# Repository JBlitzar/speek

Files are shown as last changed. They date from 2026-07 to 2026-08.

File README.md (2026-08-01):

# speek

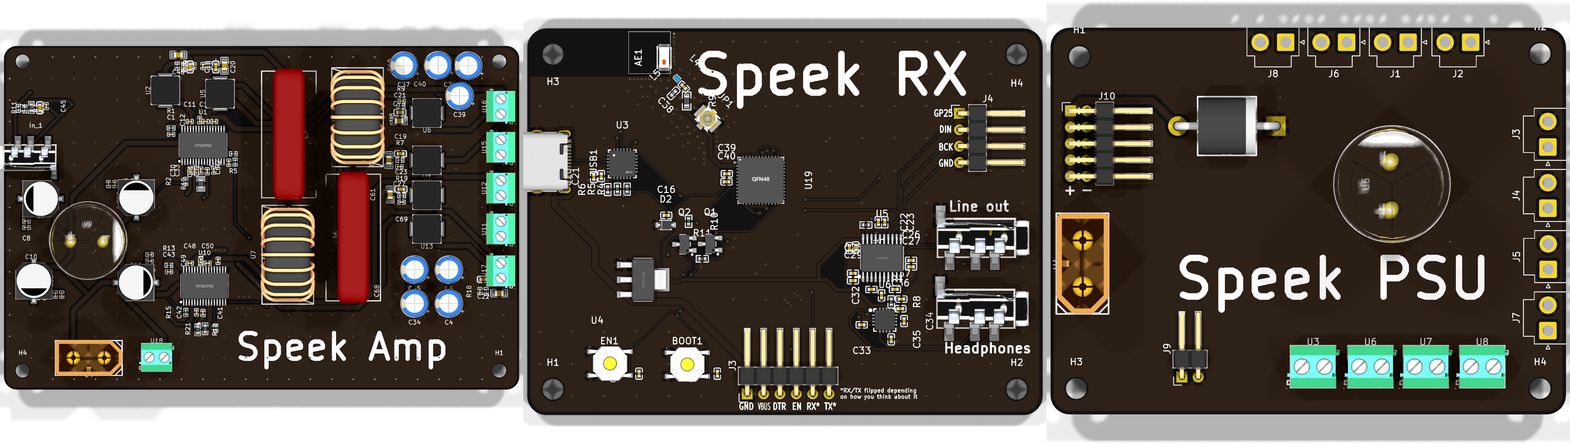
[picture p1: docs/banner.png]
speek


A modular speaker system. Right now, it has a couple of boards:

- Speek Amp: This is the flagship amplifier. It's a hybrid 2.1 design using the TPA3116D2 chip. It's built to handle 4Ω speakers. It outputs lines for a mono subwoofer, two stereo woofers, and two stereo tweeters.
- Speek RX: This is a Bluetooth audio receiver. It runs off of a qfn esp32 D0WD v3 and has a built-in headphone amp, or a normal line out for chaining.
- Speek PSU: This is a supporting PSU board. It has a USB-C PD trigger (for quick tests) and a barrel jack port for proper power (needed to power real flagship drivers). It can be used as a stable power source for pretty much anything. Note that the barrel jack supplies 24V while PD gives 20V. 

On modularity:

- Each board is self-contained and can be used on its own. However, they can also all be used together. 

I made this project to get into audio systems! I've visited some hi-fi listening rooms, and I thought it was really cool. But I think the speaker industry is way overpriced. People commonly pay several thousand dollars for nice speaker systems! I wanted to build one myself for a few hundred. It might not be as high-fidelity, but it'll be my own, which is pretty cool. And you or I probably wouldn't be able to hear the difference. 

**Right now, enclosure design is out of scope. This repo holds just the boards, and the boards are complete**

## \[Please Read\] Where do I find everything? AKA checklist

What's with the monorepo?

A monorepo just means everything lives in one repo instead of splitting each board into its own. All the files are here: each board gets its own top-level folder (`speek-amp`, `speek-rx`, `speek-psu`), with docs in `docs` and the overall BOM at `BOM.csv`. I went with a monorepo because even though there are multiple boards, it's really one project overall, so it made sense to keep them together.

Checklist:

- [x] A good README
- [x] Source files for your project
    - This includes hardware design, firmware, 3D assemblies, etc
- [x] Production files (if applicable)
    - You'll find gerbers, fabrication BOMs, and PnP files at the following locations:
      - Speek Amp: [speek-amp/PCB/speek_amp/production_real](speek-amp/PCB/speek_amp/production_real)
      - Speek RX: [speek-rx/PCB/speek_rx/production_real](speek-rx/PCB/speek_rx/production_real)
      - Speek PSU: [speek-psu/PCB/speek_psu/production_real](speek-psu/PCB/speek_psu/production_real)
- \[N/A\] JOURNAL.md if journalling on Git
- [x] BOM.csv complete with functioning links (where applicable)
- [x] A short description of what your project is
- [x] A couple sentences on why you made the project
- [x] PICTURES OF YOUR PROJECT
- [x] A screenshot of your PCB, if you have one
- [x] A screenshot of your schematic, if you have one
- [x] A wiring diagram, if you're doing any wiring that isn't on a PCB
- [x] A BOM in table format at the end of the README
- [x] A STEP file of your assembly: [speek_assembly.step](docs/speek_assembly.step)

## How to use?

Mostly it's plug-and-play after assembling everything. The exception is Speek RX, which requires firmware to be flashed. See [speek-rx/README.md](speek-rx/README.md) for more info, but in short, all you should need to do is

```bash
cd speek-rx
cd firmware
pio run -t upload
```

For wiring your speaker drivers, the silkscreen should coach you through that. 

## Wiring Diagram

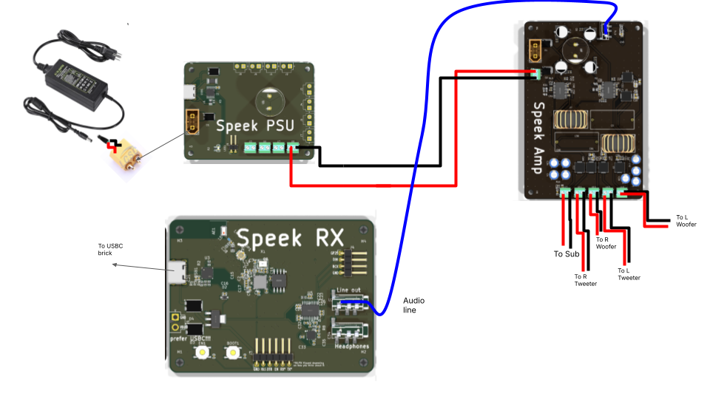
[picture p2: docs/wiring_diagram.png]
Wiring Diagram


## Gallery

### Speek Amp

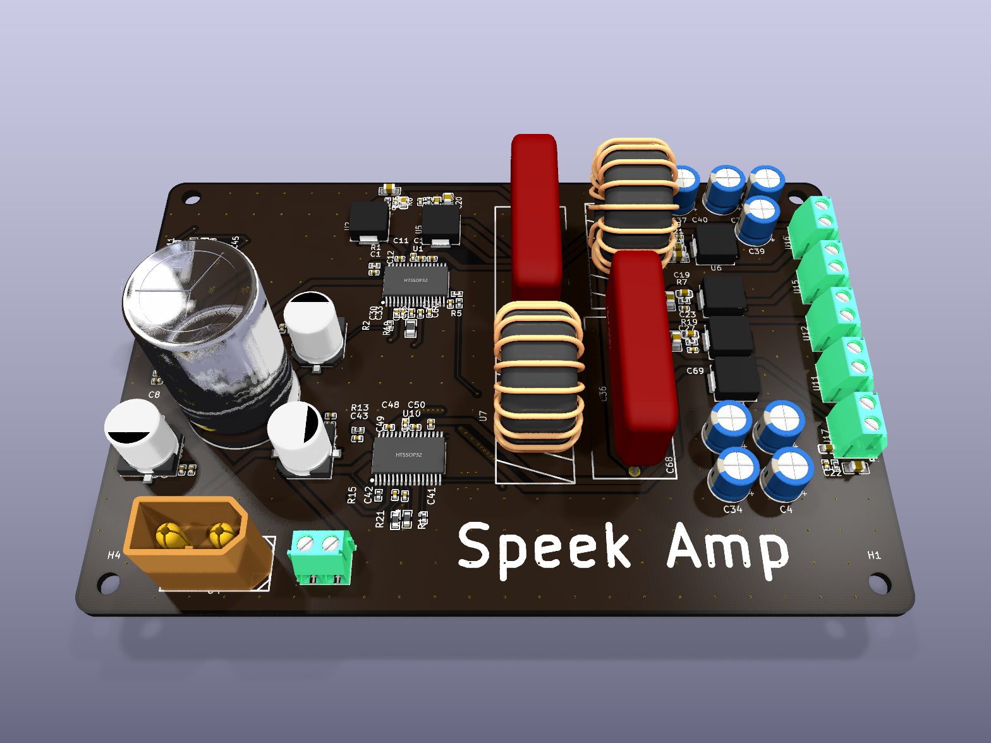
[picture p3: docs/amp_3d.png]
Speek Amp 3D render


### Speek RX

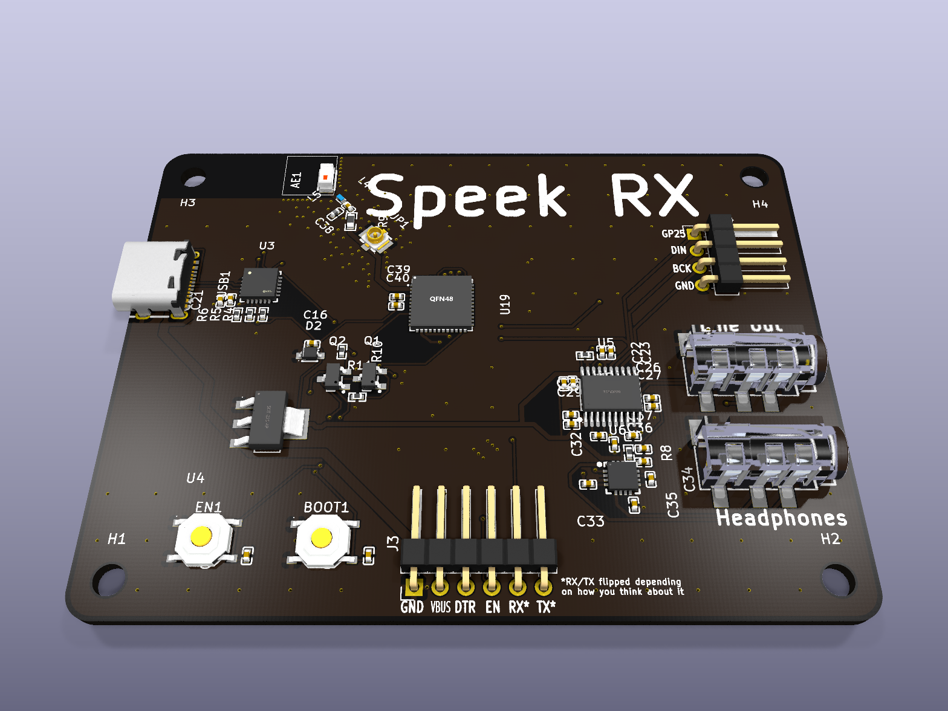
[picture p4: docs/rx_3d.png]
Speek RX 3D render


### Speek PSU

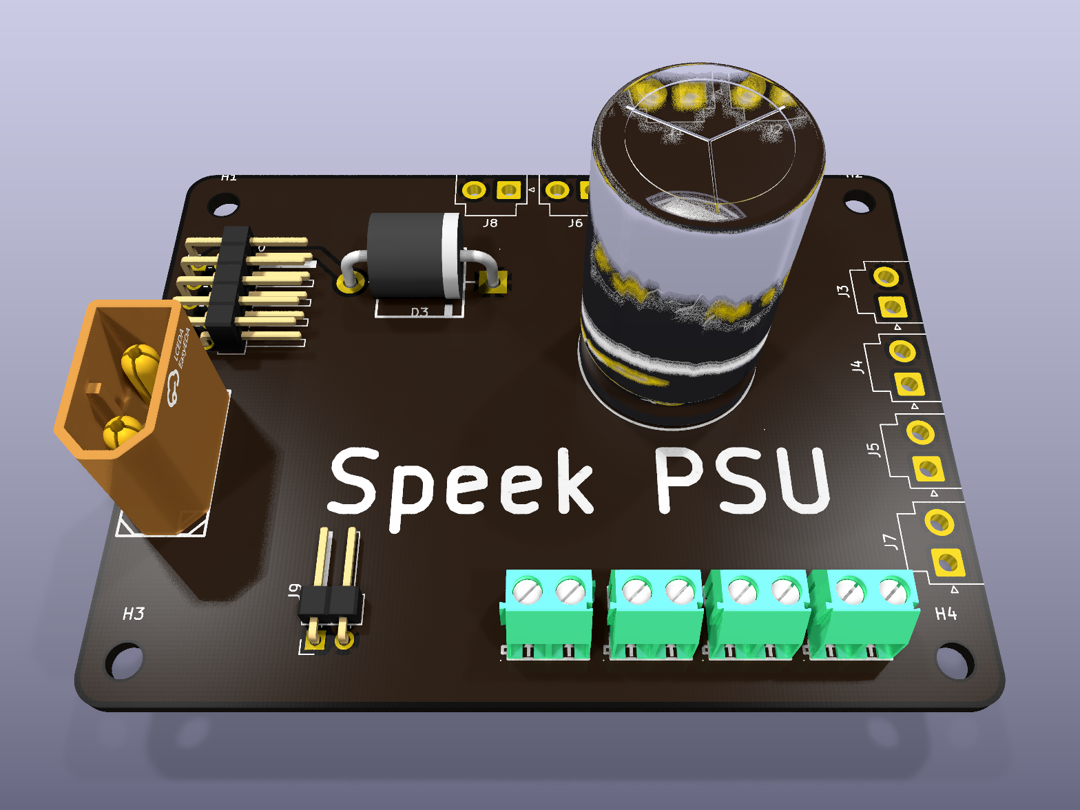
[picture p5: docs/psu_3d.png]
Speek PSU 3D render


## Schematics

### Speek Amp

[View on KiCanvas](https://kicanvas.org/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)

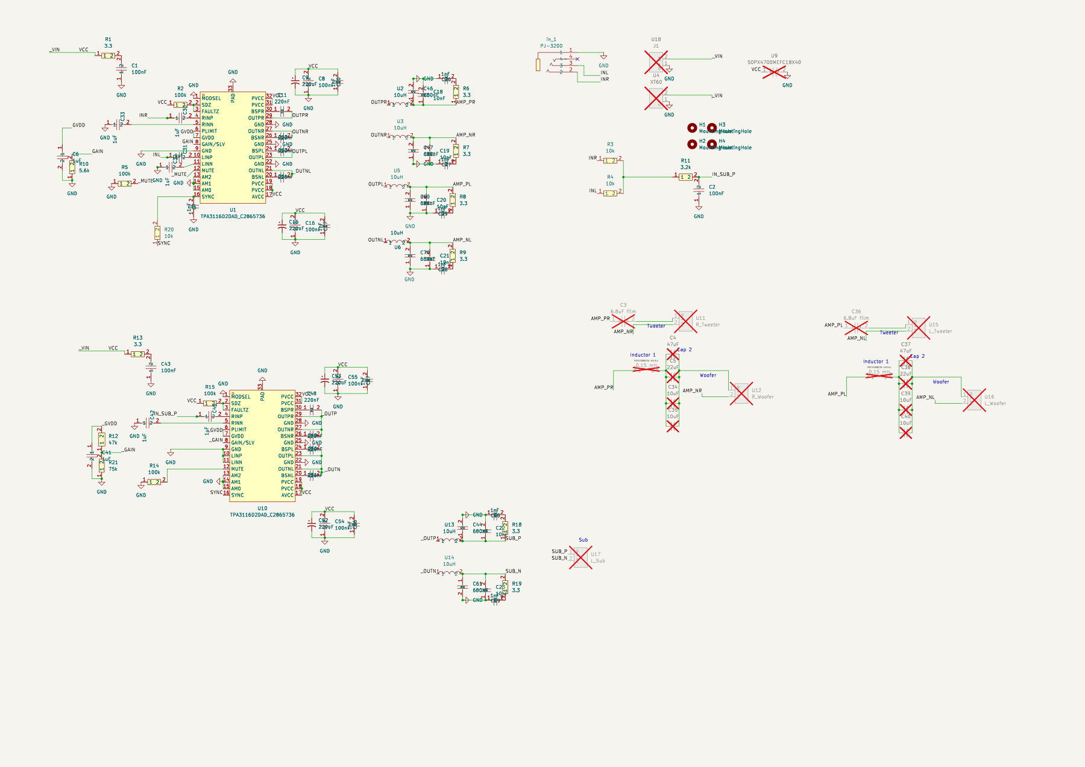
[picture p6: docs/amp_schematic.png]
Speek Amp schematic


### Speek RX

[View on KiCanvas](https://kicanvas.org/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)

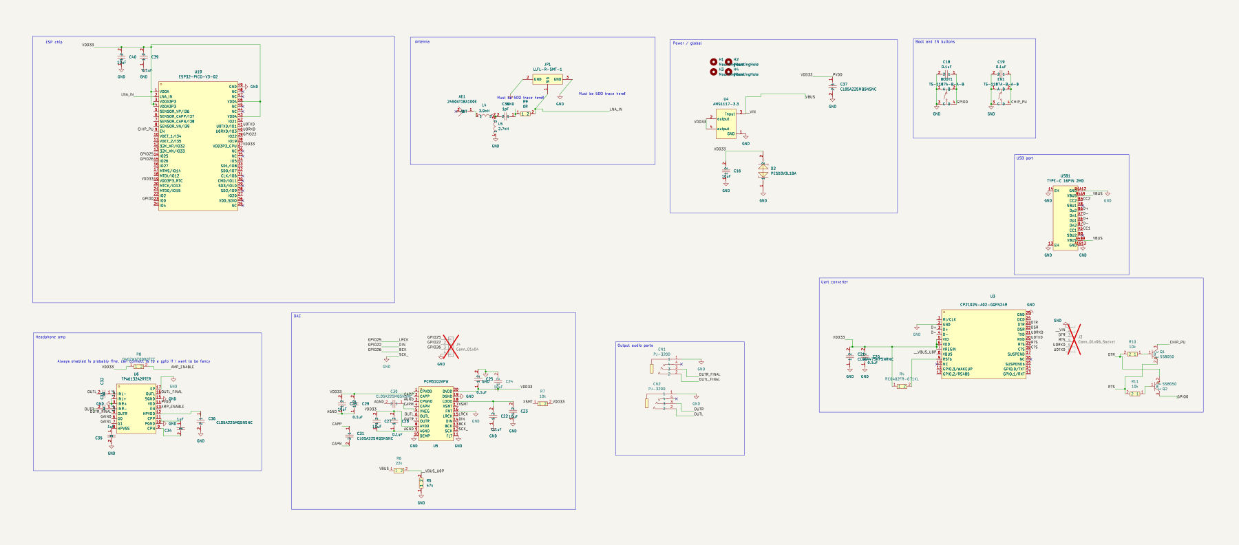
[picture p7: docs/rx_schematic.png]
Speek RX schematic


### Speek PSU

[View on KiCanvas](https://kicanvas.org/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)

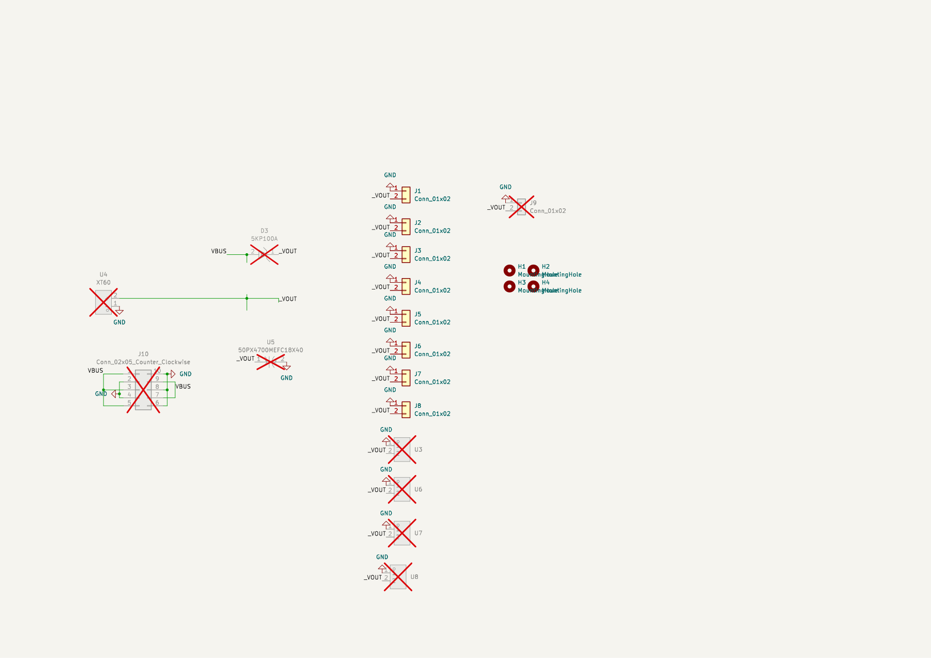
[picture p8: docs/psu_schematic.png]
Speek PSU schematic


## PCBs

### Speek Amp

[View on KiCanvas](https://kicanvas.org/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)

| F.Cu | B.Cu |
| --- | --- |
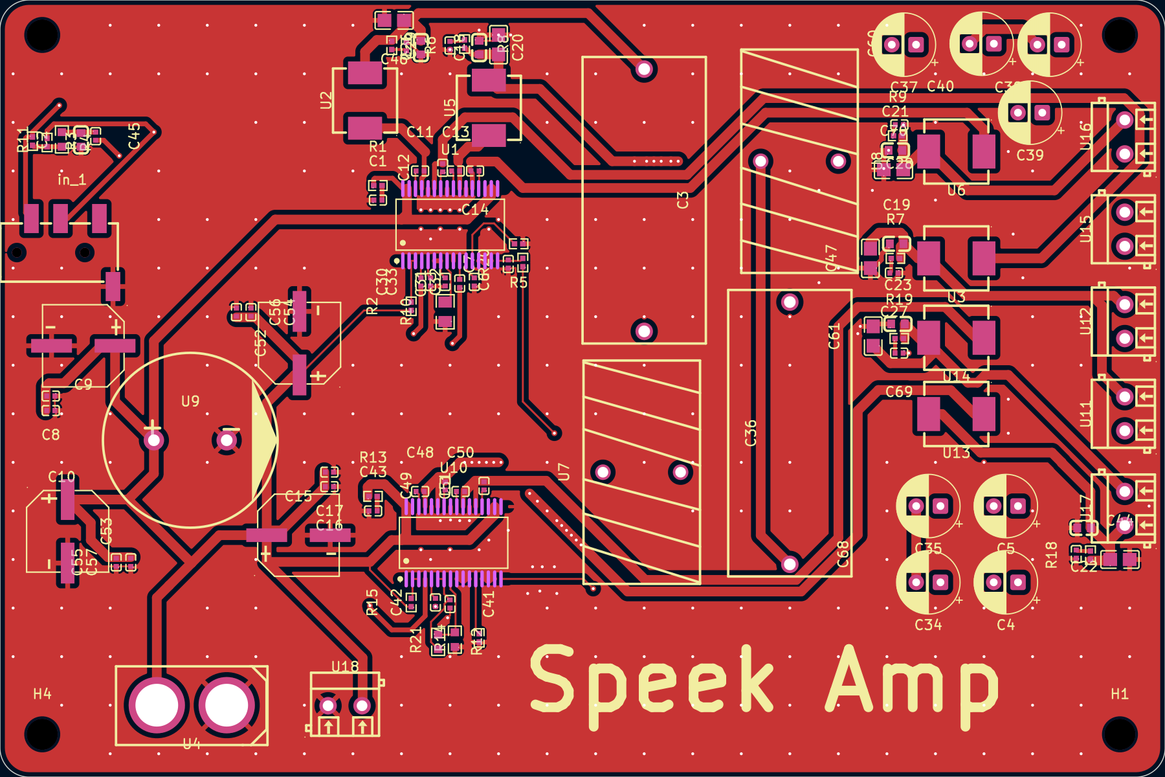
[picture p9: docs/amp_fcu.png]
Speek Amp F.Cu
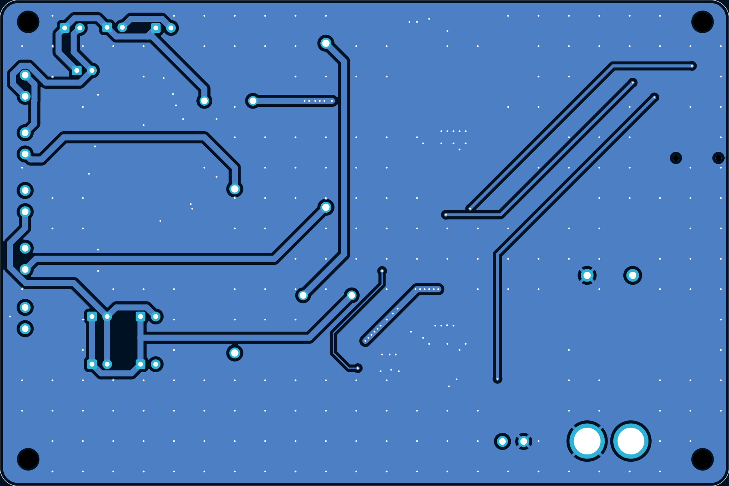
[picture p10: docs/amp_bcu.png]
Speek Amp B.Cu
|  |  |

### Speek RX

[View on KiCanvas](https://kicanvas.org/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)

| F.Cu | B.Cu |
| --- | --- |
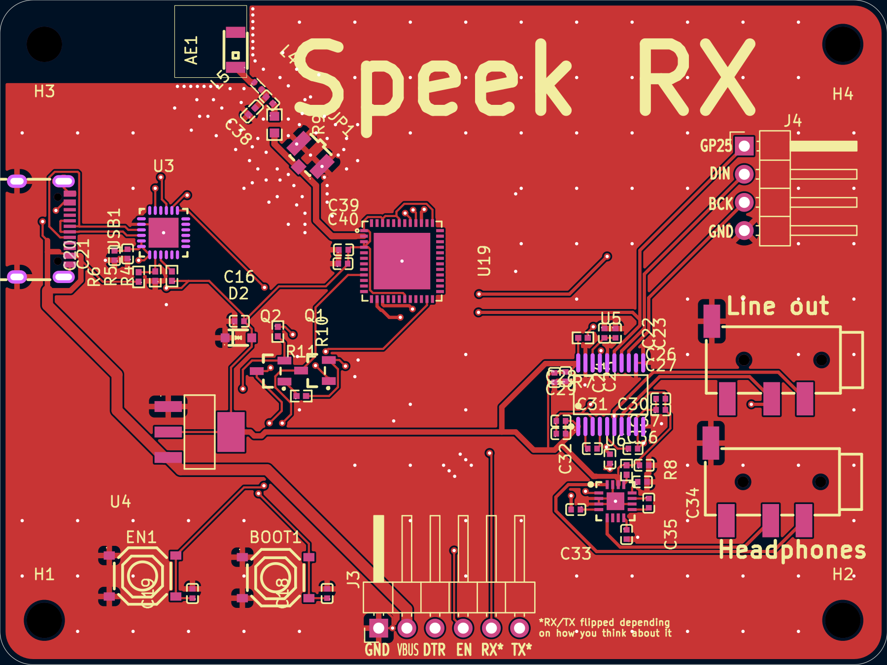
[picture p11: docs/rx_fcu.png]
Speek RX F.Cu
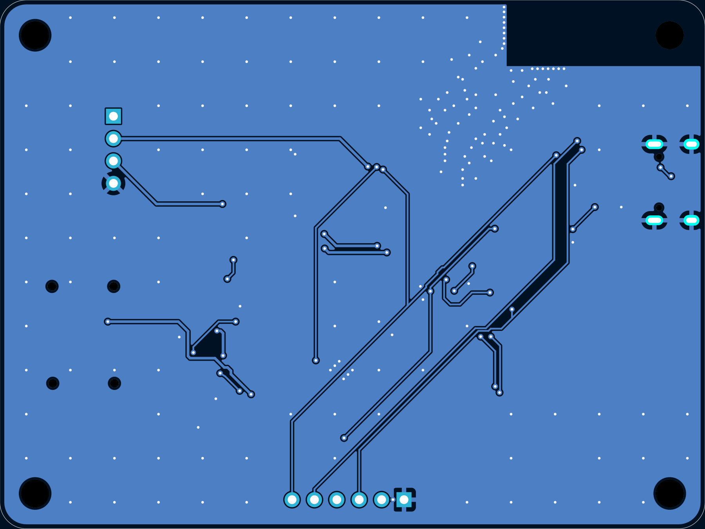
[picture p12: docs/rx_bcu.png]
Speek RX B.Cu
|  |  |

### Speek PSU

[View on KiCanvas](https://kicanvas.org/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)

| F.Cu | B.Cu |
| --- | --- |
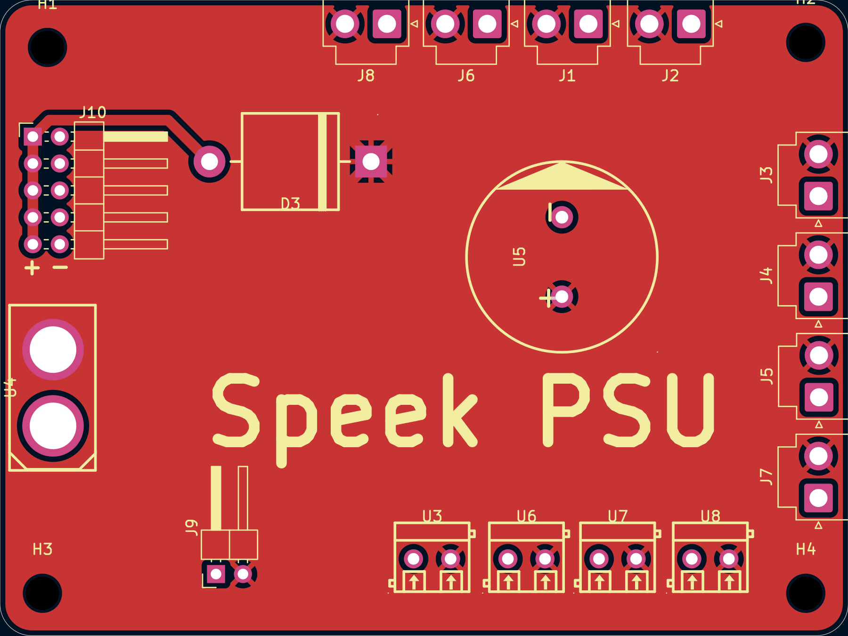
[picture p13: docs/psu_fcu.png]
Speek PSU F.Cu
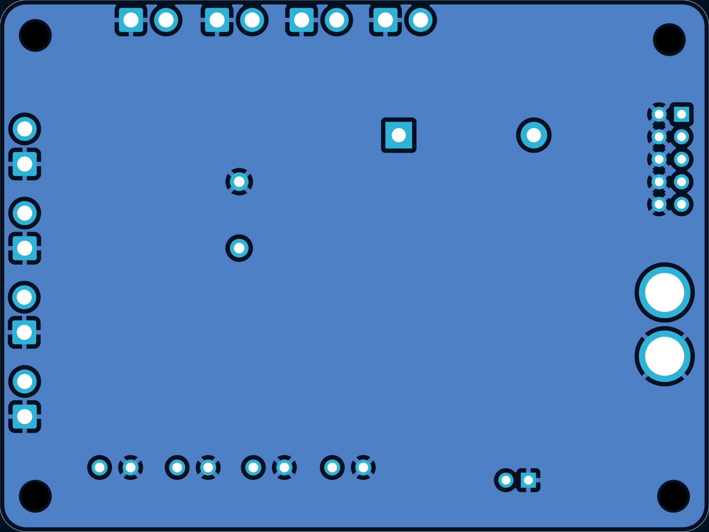
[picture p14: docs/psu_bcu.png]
Speek PSU B.Cu
|  |  |

## About cost

Speaker drivers are included in the BOM, but I'm not asking for them here. I will for sure pay for them out of pocket or figure it out. They are included in the BOM for record-keeping purposes. Basically they are the drivers that I sourced to base the amp design off of. 

For the rest, I have a significant amount of credits already lying around, and I've got a JLC $20 coupon. 

**TLDR:** I've heavily BOM-optimized and this is pretty much how much the PCBs are going to cost. Don't worry about the grant not covering everything, I'll pay the rest out of pocket

## Overall BOM

| Item | Link | Extended Cost | Notes |
| --- | --- | --- | --- |
| Notes | N/A | 0 | Will use some thick wire (already own) for all PSU bodge jobs. Speek RX must be 1mm thick PCB for antenna impedence matching! Subwoofer needs 1 cubic foot enclosure. |
| U.FL antenna | TBD | 0 | get this if the ceramic antenna doesnt work |
| 24v 6A PSU | https://www.amazon.com/Supply-Adapter-100-240V-Transformers-Security/dp/B0CGHSTDYM | 16 |  |
| XT60 male | https://www.lcsc.com/product-detail/C98733.html | 5 |  |
| XT60 female | https://www.lcsc.com/product-detail/C98734.html | 5 |  |
| JST VH connectors | https://www.amazon.com/pzsmocn-Extension-Accessories-Connector-Pre-Crimped/dp/B0DNPY3G91/ | 10 |  |
| preliminary subwoofer | https://www.parts-express.com/GRS-8SW-4-8-Poly-Cone-Subwoofer-4-Ohm-292-480?quantity=1 | 24 | [Note that I'm going to pay out of pocket for speaker drivers] Gamut runs $20 thru $50: see https://www.parts-express.com/speaker-components/hi-fi-woofers-subwoofers-midranges-tweeters/subwoofer-drivers/nominaldiameter/5-1--SLASH--4,6,6-1--SLASH--2,8?order=base_price:asc&base_price=0.00to78.49 ; pay $50 for fancier one https://www.parts-express.com/Dayton-Audio-SD215A-88-8-DVC-Subwoofer-295-484?quantity=1 |
| preliminary 2x woofers | https://www.parts-express.com/6-1-2-Poly-Cone-Woofer-4-Ohm-299-609?quantity=1 | 19.96 | [Note that I'm going to pay out of pocket for speaker drivers]  https://www.parts-express.com/reviewrating/4to5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 . More expensive non-buyout option is https://www.parts-express.com/GRS-8PR-8-8-Poly-Cone-Rubber-Surround-Woofer-292-428?quantity=1 |
| preliminary 2x tweeters | https://www.parts-express.com/Dayton-Audio-ND20FA-6-3-4-Soft-Dome-Neodymium-Tweeter-275-030?quantity=1 | 21.96 | [Note that I'm going to pay out of pocket for speaker drivers]  https://www.parts-express.com/reviewrating/4to5?keywords=tweeter&base_price=0.00to24.71 ; There exists a $4 per listing |
| 47uF caps | https://www.lcsc.com/product-detail/C397097.html | 0.76 | Buying straight from LCSC to hand-solder instead of PCBAing |
| 22uF caps | https://www.lcsc.com/product-detail/C216548.html | 0.53 | Buying straight from LCSC to hand-solder instead of PCBAing |
| 10uF caps | https://www.lcsc.com/product-detail/C192100.html | 0.74 | Buying straight from LCSC to hand-solder instead of PCBAing |
| 6.8uF film caps | https://www.lcsc.com/product-detail/C21390242.html | 1.87 | Buying straight from LCSC to hand-solder instead of PCBAing |
| 150uH inductor | https://www.lcsc.com/product-detail/C3011544.html | 1.02 | Buying straight from LCSC to hand-solder instead of PCBAing |
| 2x 4700uF cap | https://www.lcsc.com/product-detail/C5115284.html | 3.86 | Buying straight from LCSC to hand-solder instead of PCBAing |
| 1x tht diode | https://www.lcsc.com/product-detail/C522740.html | 0.72 | Buying straight from LCSC to hand-solder instead of PCBAing |
| 10x screw terminal | https://www.lcsc.com/product-detail/C695629.html | 0.84 | Buying straight from LCSC to hand-solder instead of PCBAing |
| LCSC shipping | N/A | 18.37 |  |
| Speek Amp PCB | N/A | 8.6 |  |
| Speek Amp PCBA | N/A | 45.18 |  |
| Speek RX PCB | N/A | 4 |  |
| Speek RX PCBA | N/A | 73.48 |  |
| Speek PSU PCB | N/A | 2 |  |
| JLC Shipping | N/A | 29 |  |
| Total |  | 292.89 |  |
| Total (excluding speaker drivers) |  | 226.97 |  |
| PCB total |  | 190.97 |  |

## Fabrication BOMs

> LCSC part numbers missing? Don't worry, it's a DNP component that I'll hand solder myself. It's in the table above.

### Speek Amp

| Designator | Footprint | Quantity | Value | LCSC Part # |
| --- | --- | --- | --- | --- |
| C1, C16, C43, C54, C55, C8 | C0402 | 6 | 100nF | C307331 |
| C10, C17, C26, C27, C28, C29, C56, C57, C68, C69, C7 | C0402 | 11 | 1nF | C1523 |
| C11, C12, C13, C14, C48, C49, C50, C51 | C0402 | 8 | 220nF | C16772 |
| C15, C52, C53, C9 | CAP-SMD_BD8.0-L8.3-W8.3-FD | 4 | 220uF | C178534 |
| C18, C19, C20, C21, C22, C23 | C0603 | 6 | 10nF | C57112 |
| C2 | C0603 | 1 | 100nF | C14663 |
| C3, C36 | CAP-TH_L29.5-W12.7-P27.00-D0.8 | 2 | 6.8uF film | C21390242 |
| C30, C31, C32, C33, C41, C42, C45, C6 | C0402 | 8 | 1uF | C52923 |
| C34, C35, C39, C40 | CP_Radial_D6.3mm_P2.50mm | 4 | 10uF |  |
| C37, C4 | CP_Radial_D6.3mm_P2.50mm | 2 | 47uF |  |
| C38, C5 | CP_Radial_D6.3mm_P2.50mm | 2 | 22uF |  |
| C44, C46, C47, C60, C61, C70 | C0805 | 6 | 680nF | C107133 |
| IN_1 | AUDIO-SMD_PJ-320D-1 | 1 | PJ-320D | C431535 |
| R1, R13, R18, R19, R6, R7, R8, R9 | R0402 | 8 | 3.3 | C137986 |
| R10 | R0805 | 1 | 5.6k | C4382 |
| R11 | R0603 | 1 | 3.2k | C861375 |
| R12 | R0603 | 1 | 47k | C25819 |
| R14, R15, R2, R5 | R0402 | 4 | 100k | C25741 |
| R20, R3, R4 | R0402 | 3 | 10k | C25744 |
| R21 | R0603 | 1 | 75k | C23242 |
| U1, U10 | HTSSOP-32_L11.0-W6.1-P0.65-LS8.1-BL | 2 | TPA3116D2DAD_C2865736 | C2865736 |
| U11 | CONN-TH_DB301V-3.5-2P-GN | 1 | R_Tweeter | C695629 |
| U12 | CONN-TH_DB301V-3.5-2P-GN | 1 | R_Woofer | C695629 |
| U13, U14, U2, U3, U5, U6 | IND-SMD_L7.2-W6.6_GPSR07X0 | 6 | 10uH | C5189958 |
| U15 | CONN-TH_DB301V-3.5-2P-GN | 1 | L_Tweeter | C695629 |
| U16 | CONN-TH_DB301V-3.5-2P-GN | 1 | L_Woofer | C695629 |
| U17 | CONN-TH_DB301V-3.5-2P-GN | 1 | L_Sub | C695629 |
| U18 | CONN-TH_DB301V-3.5-2P-GN | 1 | J1 | C695629 |
| U4 | CONN-TH_XT60 | 1 | XT60 | C98733 |
| U7, U8 | IND-TH_L23.0-W12.0-P8.00-D0.8 | 2 | PDMTAT068125-151MLU | C3011544 |
| U9 | CAP-TH_BD18.0-P7.50-D0.8-FD | 1 | 50PX4700MEFC18X40 | C5115284 |

### Speek RX

| Designator | Footprint | Quantity | Value | LCSC Part # |
| --- | --- | --- | --- | --- |
| AE1 | ANT-SMD_L3.2-W1.6 | 1 | 2450AT18A100E | C89334 |
| BOOT1, EN1 | SW-SMD_4P-L5.1-W5.1-P3.70-LS6.5-TL_H1.5 | 2 | TS-1187A-B-A-B | C318884 |
| C16, C23, C24, C27, C28, C40 | C0402 | 6 | 10uF | C15525 |
| C18, C19, C20, C22, C25, C26, C29, C39 | C0402 | 8 | 0.1uF | C1525 |
| C21 | C0402 | 1 | CL05A475KP5NRNC | C23733 |
| C30, C31, C36, C37 | C0402 | 4 | CL05A225MQ5NSNC | C12530 |
| C32, C33, C34, C35 | C0402 | 4 | 1uF | C52923 |
| C38 | C0402 | 1 | 1pF | C309455 |
| CN1, CN2 | AUDIO-SMD_PJ-320D-1 | 2 | PJ-320D | C431535 |
| D2 | SOD-323_L1.7-W1.3-LS2.5-BI-1 | 1 | PESD3V3L1BA | C2827682 |
| JP1 | RF-SMD_FRF05002-JSS103M | 1 | U.FL-R-SMT-1 | C88374 |
| L4 | IND-SMD_L1.0-W0.5-2 | 1 | 3.9nH | C98062 |
| L5 | L0402 | 1 | 2.7nH | C27123 |
| Q1, Q2 | SOT-23-3_L2.9-W1.5-P1.90-LS2.6-BR | 2 | SS8050 | C2150 |
| R10, R11, R7 | R0402 | 3 | 10k | C25744 |
| R4 | R0402 | 1 | RC0402FR-071KL | C11702 |
| R5 | R0402 | 1 | 47k | C25792 |
| R6 | R0402 | 1 | 22k | C25768 |
| R8 | R0402 | 1 | 0402WGF0000TCE | C17168 |
| R9 | R0603 | 1 | 0R | C21189 |
| U19 | QFN-48_L7.0-W7.0-P0.50-BL-EP5.1 | 1 | ESP32-PICO-V3-02 | C908392 |
| U3 | QFN-24_L4.0-W4.0-P0.50-TL-EP2.6 | 1 | CP2102N-A02-GQFN24R | C969151 |
| U4 | SOT-223-4_L6.5-W3.5-P2.30-LS7.0-BR | 1 | AMS1117-3.3 | C6186 |
| U5 | TSSOP-20_L6.5-W4.4-P0.65-LS6.4-BL | 1 | PCM5102APW | C1520792 |
| U6 | WQFN-16_L3.0-W3.0-P0.50-TL-EP1.6 | 1 | TPA6132A2RTER | C69901 |
| USB1 | USB-C-SMD_TYPE-C-16PIN-2MD-073 | 1 | TYPE-C 16PIN 2MD | C2765186 |

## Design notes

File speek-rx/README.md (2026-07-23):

# speek-rx
Bluetooth to 3.5mm adapter. 

## How to use

Plug the USB-C port in to your computer.

Flash:
```bash
cd firmware
pio run -t upload
```

Now you can run the usb-c port off of a power brick or whatever

Speaker should show up in bluetooth as "speek-rx." Enjoy!

Line out and headphone jack are labeled in silkscreen

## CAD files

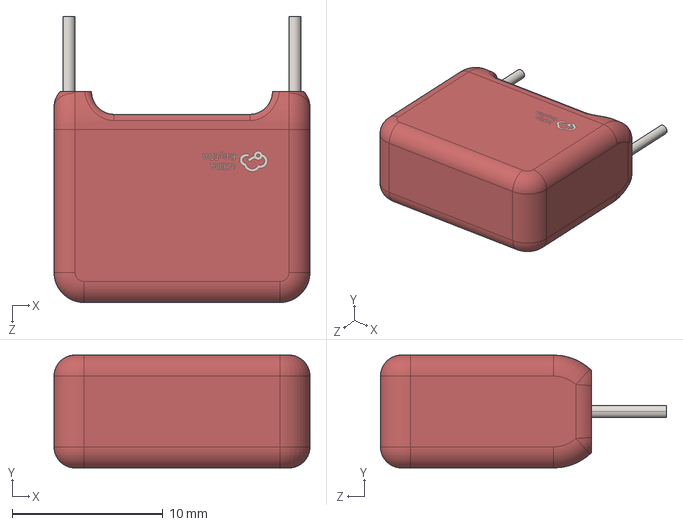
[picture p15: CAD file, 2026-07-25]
speek-amp/PCB/speek_amp/CAP-TH-2P-L17.0-W7.5-H14.0-P15.0.step
17.0 x 7.50 x 19.0 mm

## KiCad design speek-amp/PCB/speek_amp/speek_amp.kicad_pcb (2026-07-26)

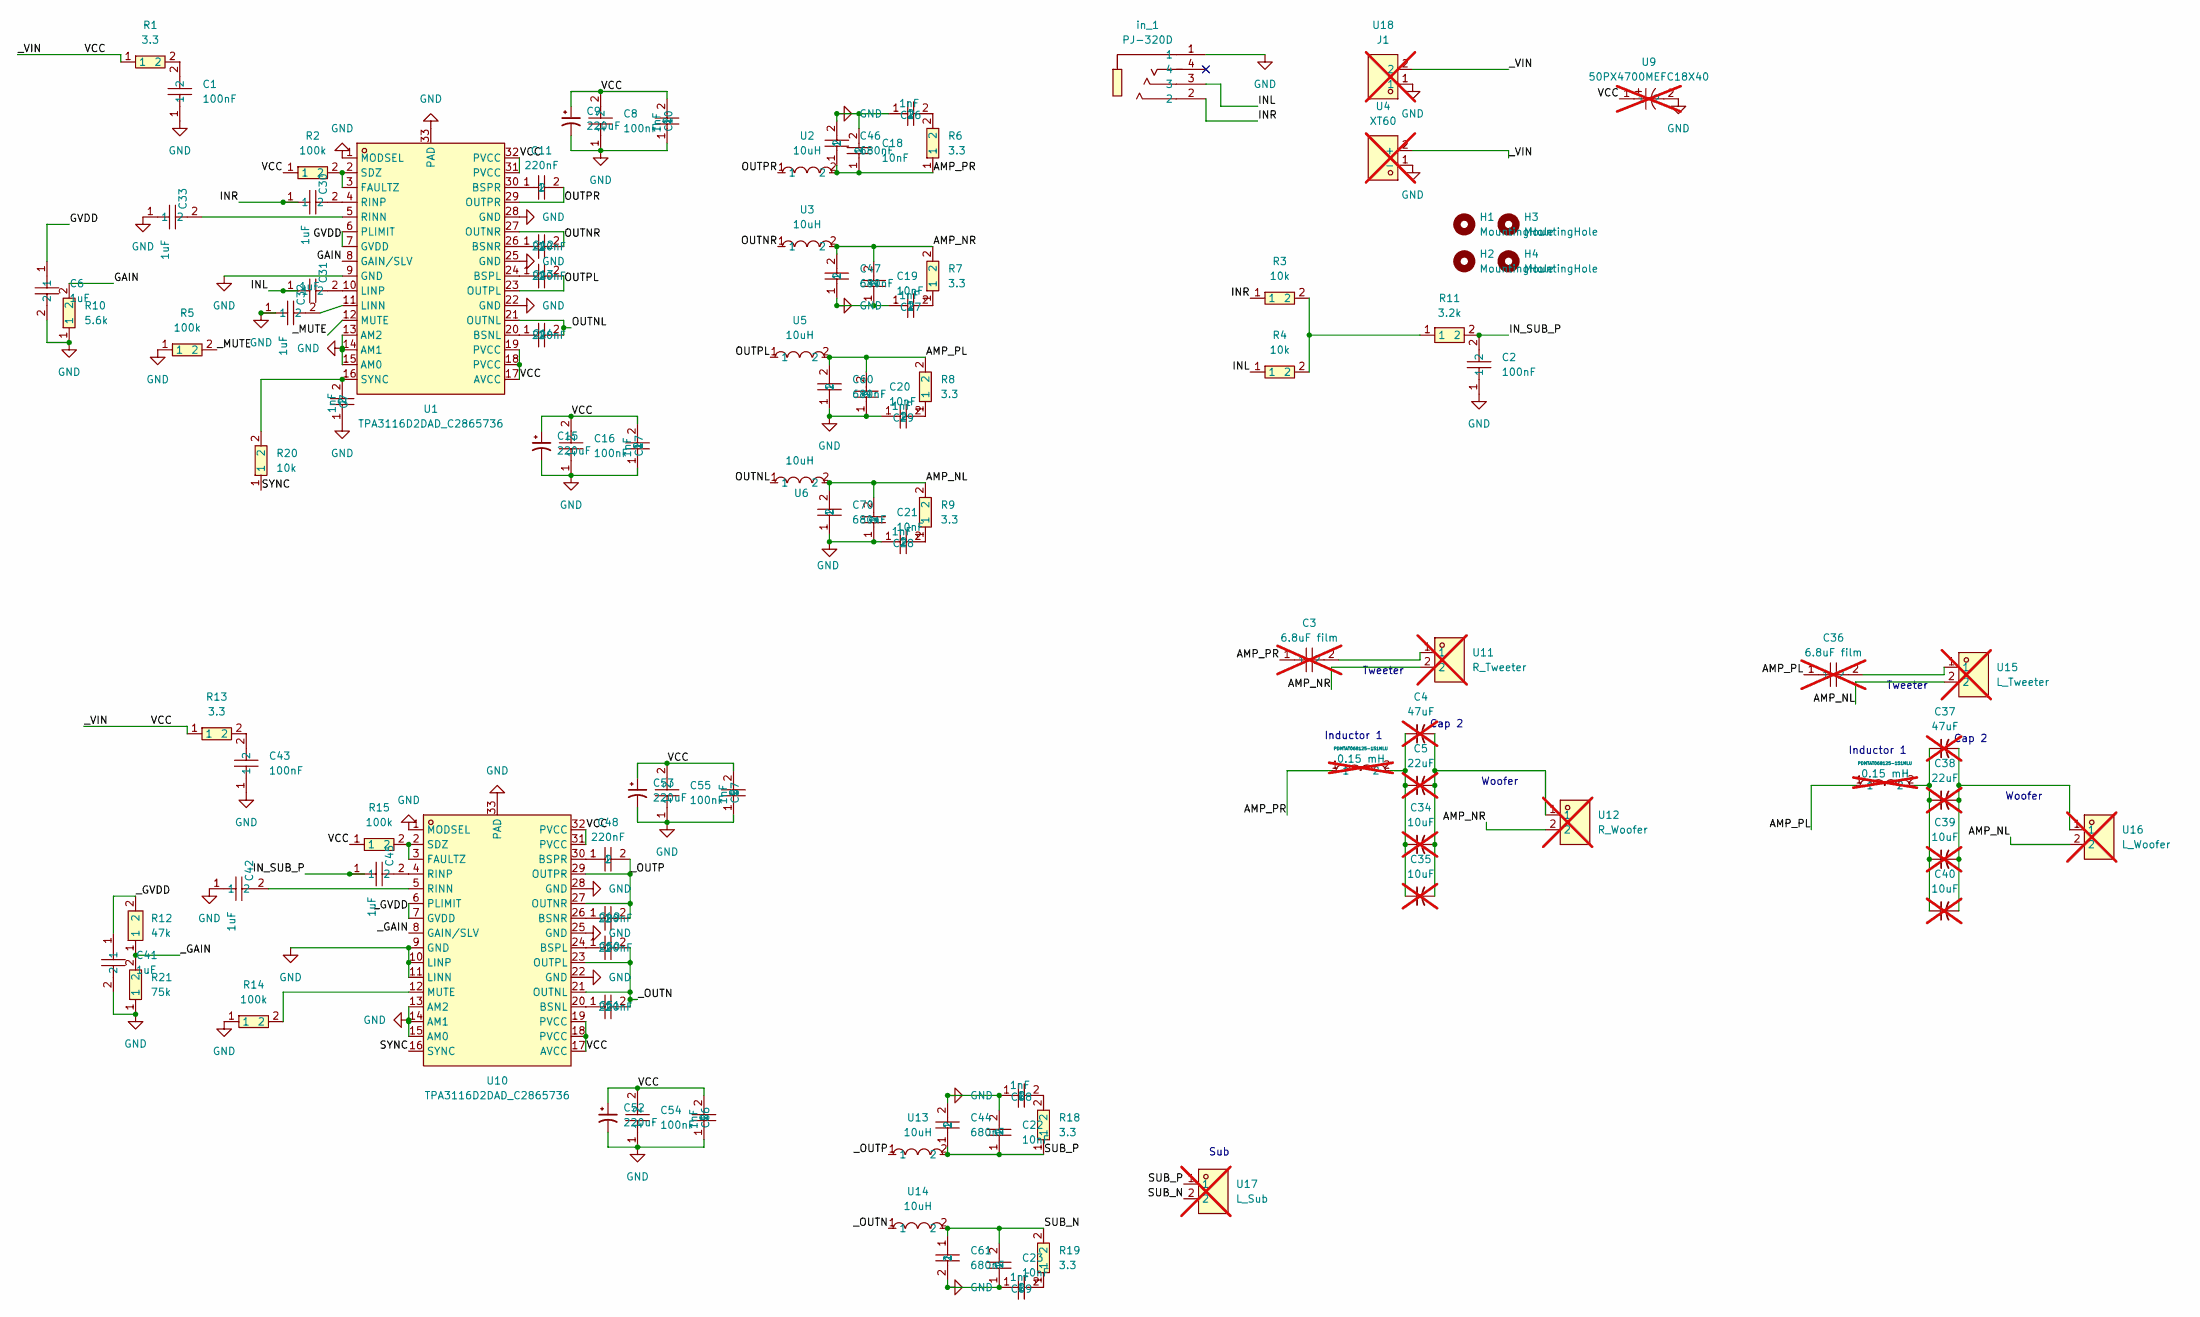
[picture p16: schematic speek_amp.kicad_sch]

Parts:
C1, C8, C16, C43, C54, C55: 100nF; C0402; MPN CL05B104KB54PNC; LCSC Part C307331
C2: 100nF; C0603; MPN CC0603KRX7R9BB104; LCSC Part C14663
C3, C36: 6.8uF film; CAP-TH_L29.5-W12.7-P27.00-D0.8; MPN W312G685JS8SA1C0EC; LCSC Part C21390242; not fitted
C4, C37: 47uF; CP_Radial_D6.3mm_P2.50mm; not fitted
C5, C38: 22uF; CP_Radial_D6.3mm_P2.50mm; not fitted
C6, C30, C31, C32, C33, C41, C42, C45: 1uF; C0402; MPN CL05A105KA5NQNC; LCSC Part C52923
C7, C10, C17, C26, C27, C28, C29, C56, C57, C68, C69: 1nF; C0402; MPN 0402B102K500NT; LCSC Part C1523
C9, C15, C52, C53: 220uF; CAP-SMD_BD8.0-L8.3-W8.3-FD
C11, C12, C13, C14, C48, C49, C50, C51: 220nF; C0402; MPN CL05B224KO5NNNC; LCSC Part C16772
C18, C19, C20, C21, C22, C23: 10nF; C0603; MPN 0603B103K500NT; LCSC Part C57112
C34, C35, C39, C40: 10uF; CP_Radial_D6.3mm_P2.50mm; not fitted
C44, C46, C47, C60, C61, C70: 680nF; C0805; MPN CC0805KKX7R9BB684; LCSC Part C107133
H1, H2, H3, H4: MountingHole; MountingHole_3.2mm_M3
R1, R6, R7, R8, R9, R13, R18, R19: 3.3; R0402; MPN RC0402FR-073R3L; LCSC Part C137986
R2, R5, R14, R15: 100k; R0402; MPN 0402WGF1003TCE; LCSC Part C25741
R3, R4, R20: 10k; R0402; MPN 0402WGF1002TCE; LCSC Part C25744
R10: 5.6k; R0805; MPN 0805W8F5601T5E; LCSC Part C4382
R11: 3.2k; R0603; MPN RT0603BRD073K2L; LCSC Part C861375
R12: 47k; R0603; MPN 0603WAF4702T5E; LCSC Part C25819
R21: 75k; R0603; MPN 0603WAF7502T5E; LCSC Part C23242
U1, U10: TPA3116D2DAD_C2865736; HTSSOP-32_L11.0-W6.1-P0.65-LS8.1-BL; MPN TPA3116D2DAD; LCSC Part C2865736
U2, U3, U5, U6, U13, U14: 10uH; IND-SMD_L7.2-W6.6_GPSR07X0; MPN CYA0630-10UH; LCSC Part C5189958
U4: XT60; CONN-TH_XT60; MPN XT60-M.; LCSC Part C98733; not fitted
U7, U8: PDMTAT068125-151MLU; IND-TH_L23.0-W12.0-P8.00-D0.8; MPN PDMTAT068125-151MLU; LCSC Part C3011544; not fitted
U9: 50PX4700MEFC18X40; CAP-TH_BD18.0-P7.50-D0.8-FD; MPN 50PX4700MEFC18X40; LCSC Part C5115284; not fitted
U11: R_Tweeter; CONN-TH_DB301V-3.5-2P-GN; MPN DB301V-3.5-2P-GN-S; LCSC Part C695629; not fitted
U12: R_Woofer; CONN-TH_DB301V-3.5-2P-GN; MPN DB301V-3.5-2P-GN-S; LCSC Part C695629; not fitted
U15: L_Tweeter; CONN-TH_DB301V-3.5-2P-GN; MPN DB301V-3.5-2P-GN-S; LCSC Part C695629; not fitted
U16: L_Woofer; CONN-TH_DB301V-3.5-2P-GN; MPN DB301V-3.5-2P-GN-S; LCSC Part C695629; not fitted
U17: L_Sub; CONN-TH_DB301V-3.5-2P-GN; MPN DB301V-3.5-2P-GN-S; LCSC Part C695629; not fitted
U18: J1; CONN-TH_DB301V-3.5-2P-GN; MPN DB301V-3.5-2P-GN-S; LCSC Part C695629; not fitted
in_1: PJ-320D; AUDIO-SMD_PJ-320D-1; MPN PJ-320D; LCSC Part C431535

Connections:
/AMP_NL: C21.2, C70.2, R9.2, U6.2, U15.2, U16.2
/AMP_NR: C19.2, C47.2, R7.2, U3.2, U11.2, U12.2
/AMP_PL: C20.2, C36.1, C60.2, R8.2, U5.2, U8.1
/AMP_PR: C3.1, C18.1, C46.1, R6.1, U2.2, U7.1
/GAIN: R10.2, U1.8 (GAIN/SLV)
/GVDD: C6.1, U1.6 (PLIMIT), U1.7 (GVDD)
/INL: C31.1, R4.1, in_1.3
/INR: C30.1, R3.1, in_1.2
/IN_SUB_P: C2.2, C45.1, R11.2
/OUTNL: C14.2, U1.21 (OUTNL), U6.1
/OUTNR: C12.2, U1.27 (OUTNR), U3.1
/OUTPL: C13.2, U1.23 (OUTPL), U5.1
/OUTPR: C11.2, U1.29 (OUTPR), U2.1
/SUB_N: C23.2, C61.1, R19.2, U14.2, U17.2
/SUB_P: C22.1, C44.1, R18.1, U13.2, U17.1
/SYNC: R20.1, U10.16 (SYNC)
/VCC: C8.2, C9.1, C10.2, C15.1, C16.2, C17.2, C52.1, C53.1, C54.2, C55.2, C56.2, C57.2, R1.1, R2.1, R13.1, R15.1, U1.17 (AVCC), U1.18 (PVCC), U1.19 (PVCC), U1.31 (PVCC), U1.32 (PVCC), U4.2 (+), U9.1, U10.17 (AVCC), U10.18 (PVCC), U10.19 (PVCC), U10.31 (PVCC), U10.32 (PVCC), U18.2
/_GAIN: R12.1, R21.2, U10.8 (GAIN/SLV)
/_GVDD: C41.1, R12.2, U10.6 (PLIMIT), U10.7 (GVDD)
/_MUTE: R5.2, U1.12 (MUTE)
/_OUTN: C50.2, C51.2, U10.21 (OUTNL), U10.23 (OUTPL), U14.1
/_OUTP: C48.2, C49.2, U10.27 (OUTNR), U10.29 (OUTPR), U13.1
GND: C1.1, C2.1, C6.2, C7.1, C8.1, C9.2, C10.1, C15.2, C16.1, C17.1, C18.2, C19.1, C20.1, C21.1, C22.2, C23.1, C26.1, C27.1, C28.1, C29.1, C32.1, C33.1, C41.2, C42.1, C43.1, C44.2, C46.2, C47.1, C52.2, C53.2, C54.1, C55.1, C56.1, C57.1, C60.1, C61.2, C68.1, C69.1, C70.1, R5.1, R10.1, R14.1, R21.1, U1.1 (MODSEL), U1.9 (GND), U1.13 (AM2), U1.14 (AM1), U1.15 (AM0), U1.22 (GND), U1.25 (GND), U1.28 (GND), U1.33 (PAD), U4.1 (-), U9.2, U10.1 (MODSEL), U10.9 (GND), U10.10 (LINP), U10.11 (LINN), U10.13 (AM2), U10.14 (AM1), U10.15 (AM0), U10.22 (GND), U10.25 (GND), U10.28 (GND), U10.33 (PAD), U18.1, in_1.1
unnamed: C1.2, R1.2
unnamed: C3.2, U11.1
unnamed: C26.2, R6.2
unnamed: C27.2, R7.1
unnamed: C28.2, R9.1
unnamed: C29.2, R8.1
unnamed: C4.1, C5.1, C34.1, C35.1, U7.2
unnamed: C4.2, C5.2, C34.2, C35.2, U12.1
unnamed: C36.2, U15.1
unnamed: C37.1, C38.1, C39.1, C40.1, U8.2
unnamed: C37.2, C38.2, C39.2, C40.2, U16.1
unnamed: C43.2, R13.2
unnamed: C68.2, R18.2
unnamed: C69.2, R19.1
unnamed: R3.2, R4.2, R11.1
unnamed: C14.1, U1.20 (BSNL)
unnamed: C12.1, U1.26 (BSNR)
unnamed: C13.1, U1.24 (BSPL)
unnamed: C11.1, U1.30 (BSPR)
unnamed: R2.2, U1.2 (SDZ), U1.3 (FAULTZ)
unnamed: C32.2, U1.11 (LINN)
unnamed: C31.2, U1.10 (LINP)
unnamed: C33.2, U1.5 (RINN)
unnamed: C30.2, U1.4 (RINP)
unnamed: C7.2, R20.2, U1.16 (SYNC)
unnamed: C51.1, U10.20 (BSNL)
unnamed: C49.1, U10.26 (BSNR)
unnamed: C50.1, U10.24 (BSPL)
unnamed: C48.1, U10.30 (BSPR)
unnamed: R15.2, U10.2 (SDZ), U10.3 (FAULTZ)
unnamed: R14.2, U10.12 (MUTE)
unnamed: C42.2, U10.5 (RINN)
unnamed: C45.2, U10.4 (RINP)

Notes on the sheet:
Inductor 1
Woofer
Tweeter
Cap 2
Sub

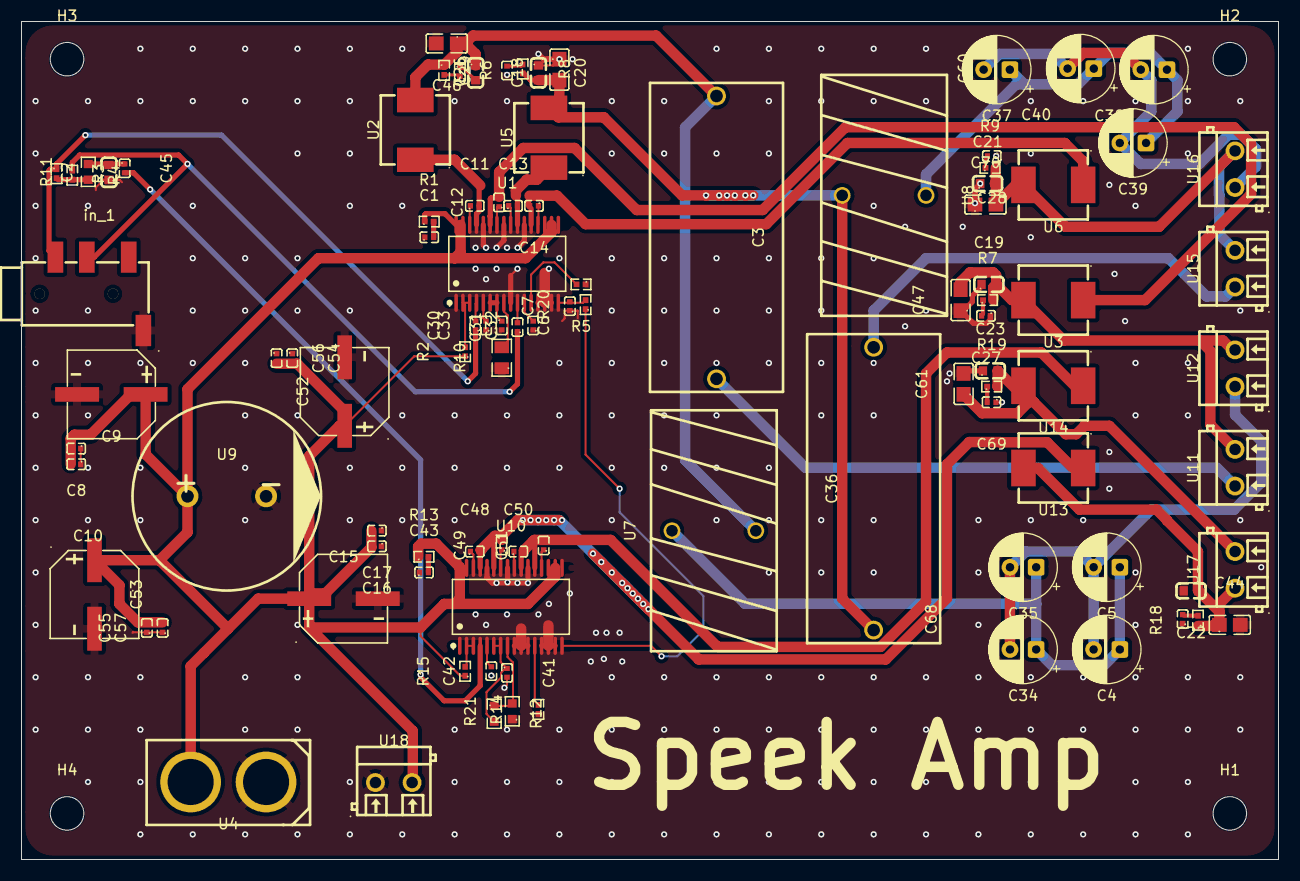
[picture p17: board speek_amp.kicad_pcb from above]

Board: 2 copper layers, 120.0 x 80.0 mm, 102 parts (0 on the bottom side), 56 nets.

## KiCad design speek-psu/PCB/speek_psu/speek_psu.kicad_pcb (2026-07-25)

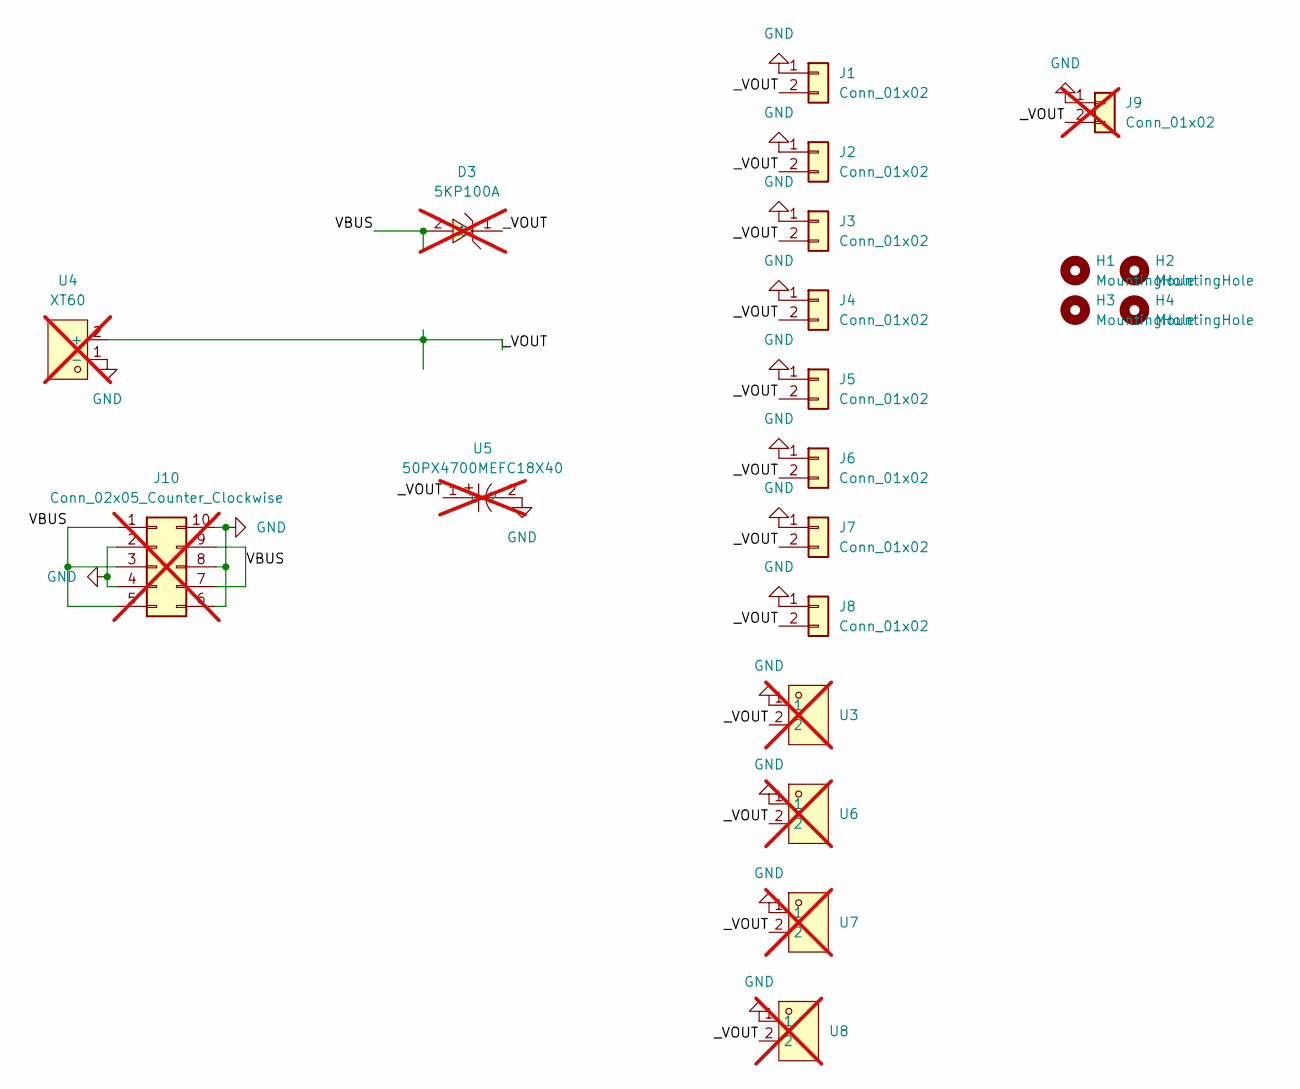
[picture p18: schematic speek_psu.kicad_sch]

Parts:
D3: 5KP100A; DIO-TH_BD8.8-L8.8-P12.8-D1.6-RD; MPN 5KP100A/B; LCSC Part C522740; not fitted
H1, H2, H3, H4: MountingHole; MountingHole_3.2mm_M3
J1, J2, J3, J4, J5, J6, J7, J8: Conn_01x02; JST_VH_B2P-VH-B_1x02_P3.96mm_Vertical
J9: Conn_01x02; PinHeader_1x02_P2.54mm_Horizontal; not fitted
J10: Conn_02x05_Counter_Clockwise; PinHeader_2x05_P2.54mm_Horizontal; not fitted
U3, U6, U7, U8: CONN-TH_DB301V-3.5-2P-GN; MPN DB301V-3.5-2P-GN-S; LCSC Part C695629; not fitted
U4: XT60; CONN-TH_XT60; MPN XT60-M.; LCSC Part C98733; not fitted
U5: 50PX4700MEFC18X40; CAP-TH_BD18.0-P7.50-D0.8-FD; MPN 50PX4700MEFC18X40; LCSC Part C5115284; not fitted

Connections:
/VBUS: D3.2 (A), J10.1, J10.3, J10.5, J10.7, J10.9
/_VOUT: D3.1 (C), J1.2, J2.2, J3.2, J4.2, J5.2, J6.2, J7.2, J8.2, J9.2, U3.2, U4.2 (+), U5.1, U6.2, U7.2, U8.2
GND: J1.1, J2.1, J3.1, J4.1, J5.1, J6.1, J7.1, J8.1, J9.1, J10.2, J10.4, J10.6, J10.8, J10.10, U3.1, U4.1 (-), U5.2, U6.1, U7.1, U8.1

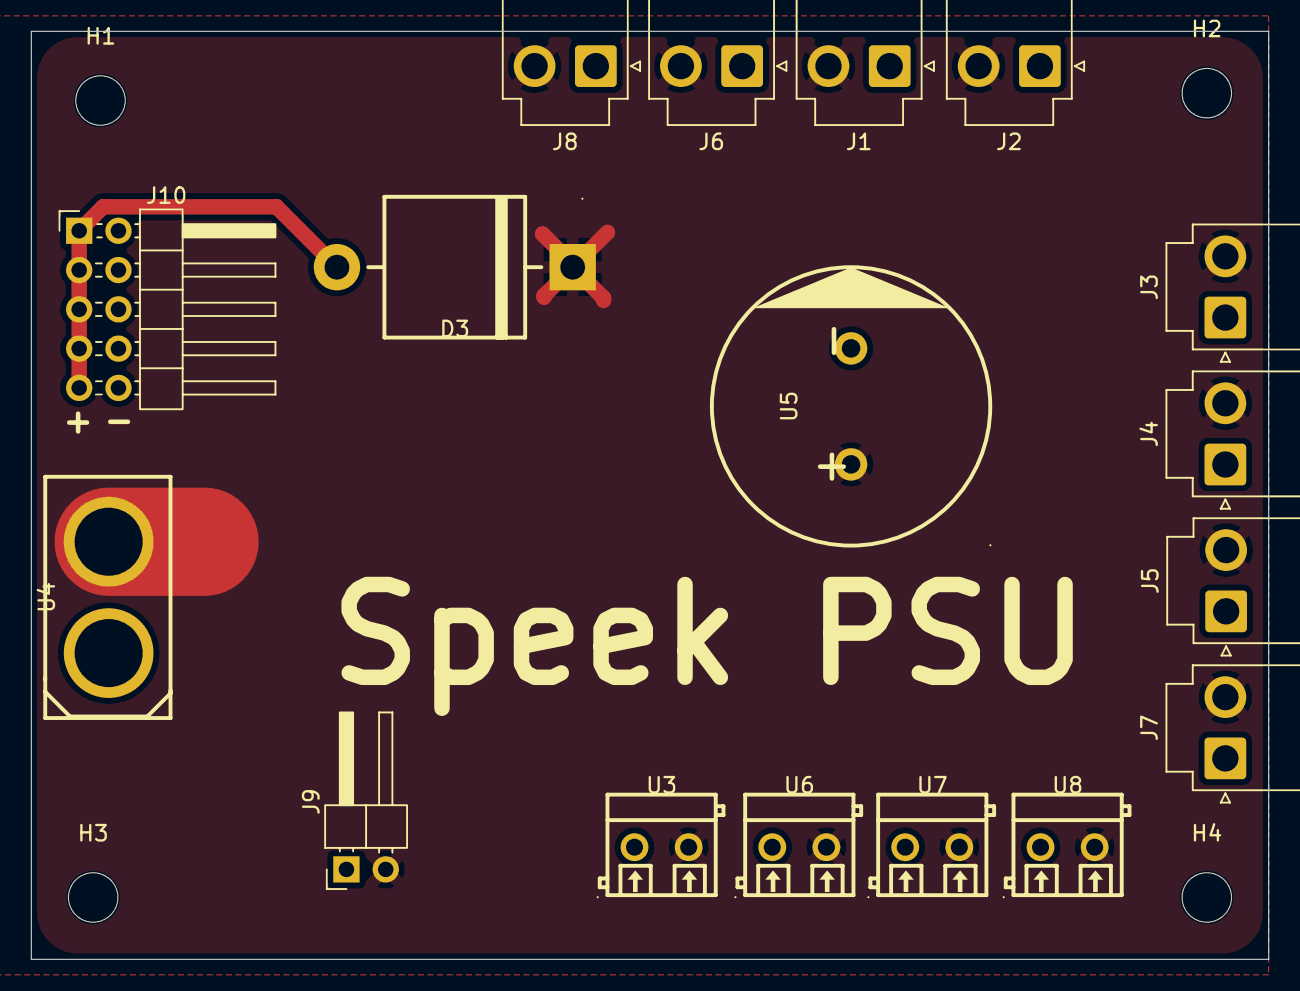
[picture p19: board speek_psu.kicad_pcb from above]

Board: 2 copper layers, 80.0 x 60.0 mm, 21 parts (0 on the bottom side), 3 nets.

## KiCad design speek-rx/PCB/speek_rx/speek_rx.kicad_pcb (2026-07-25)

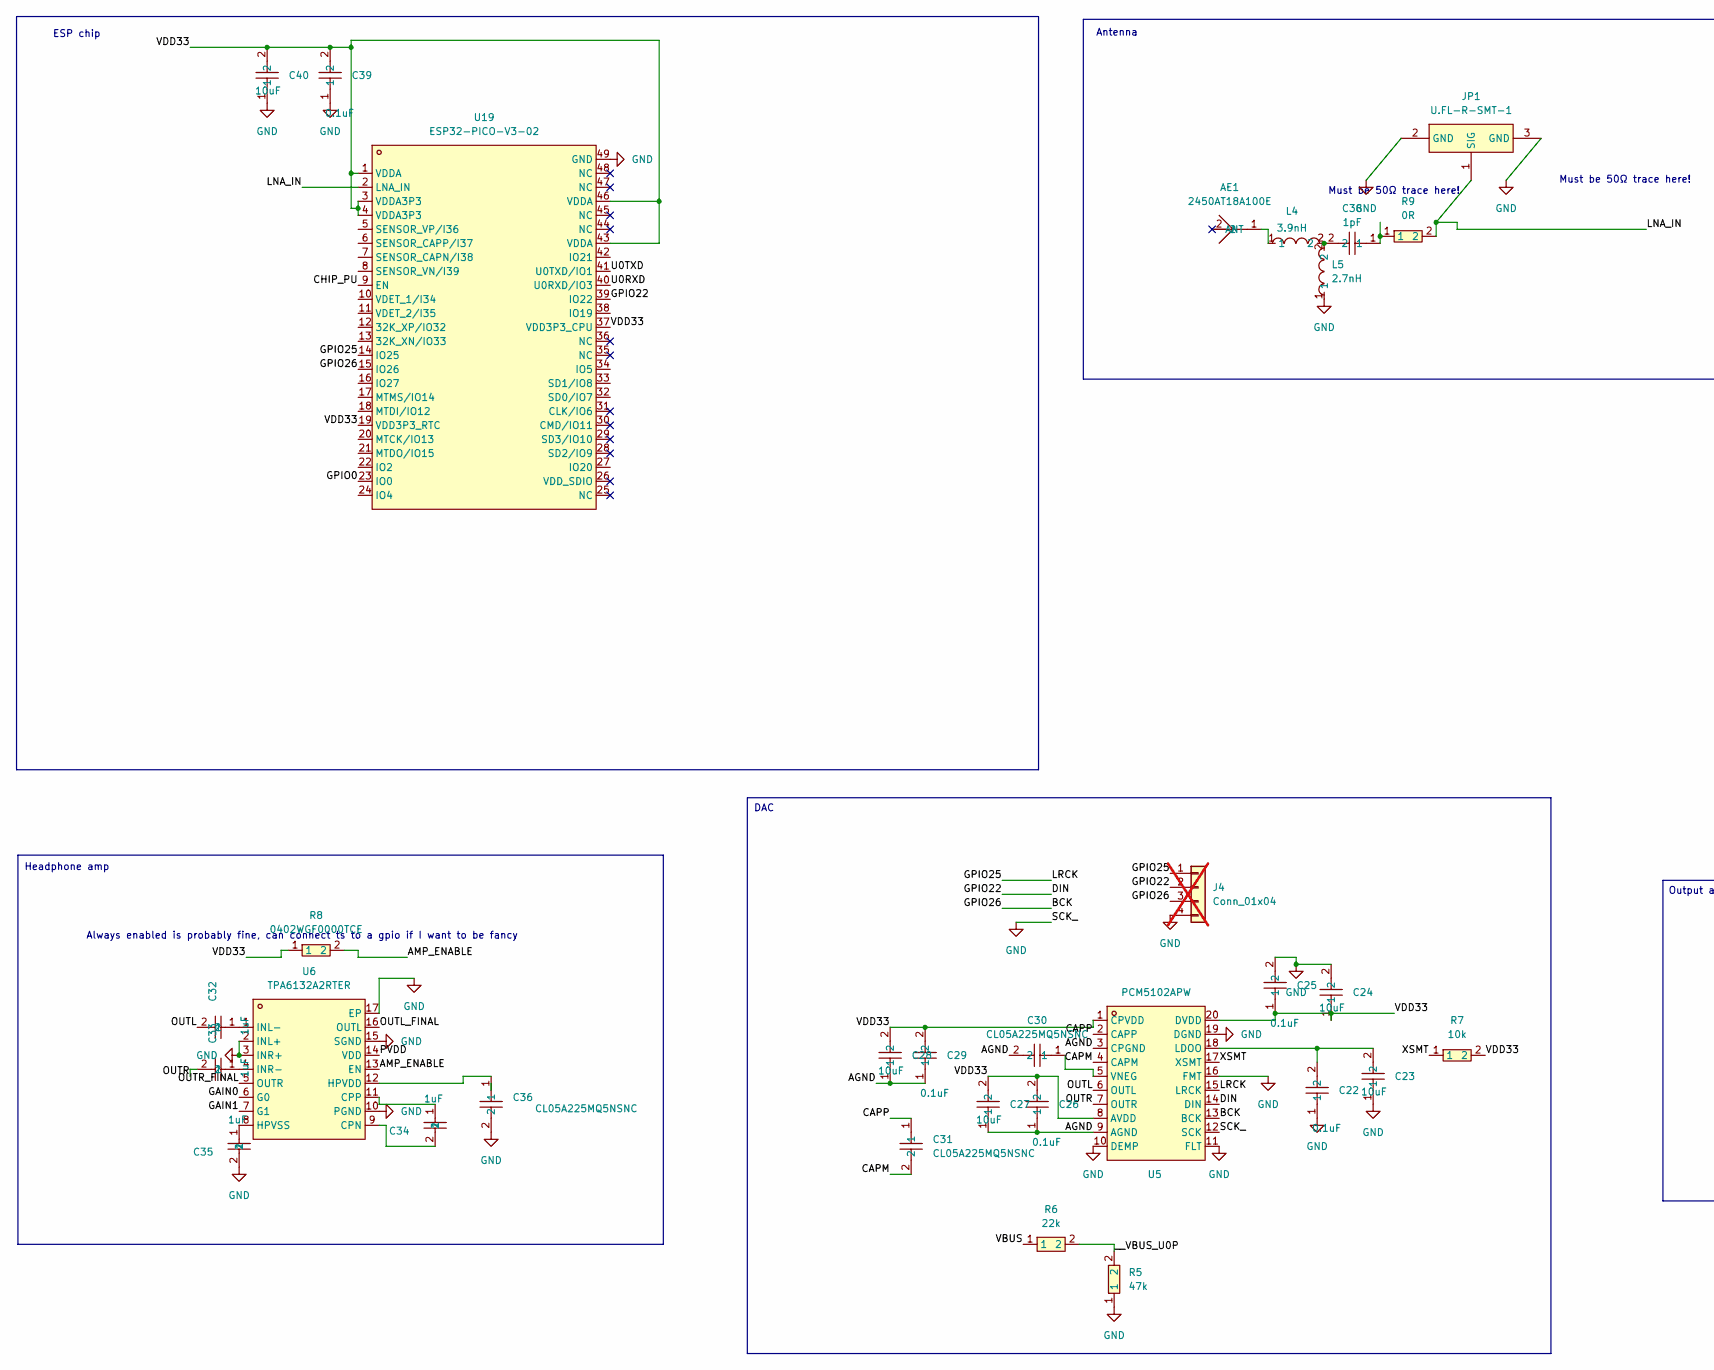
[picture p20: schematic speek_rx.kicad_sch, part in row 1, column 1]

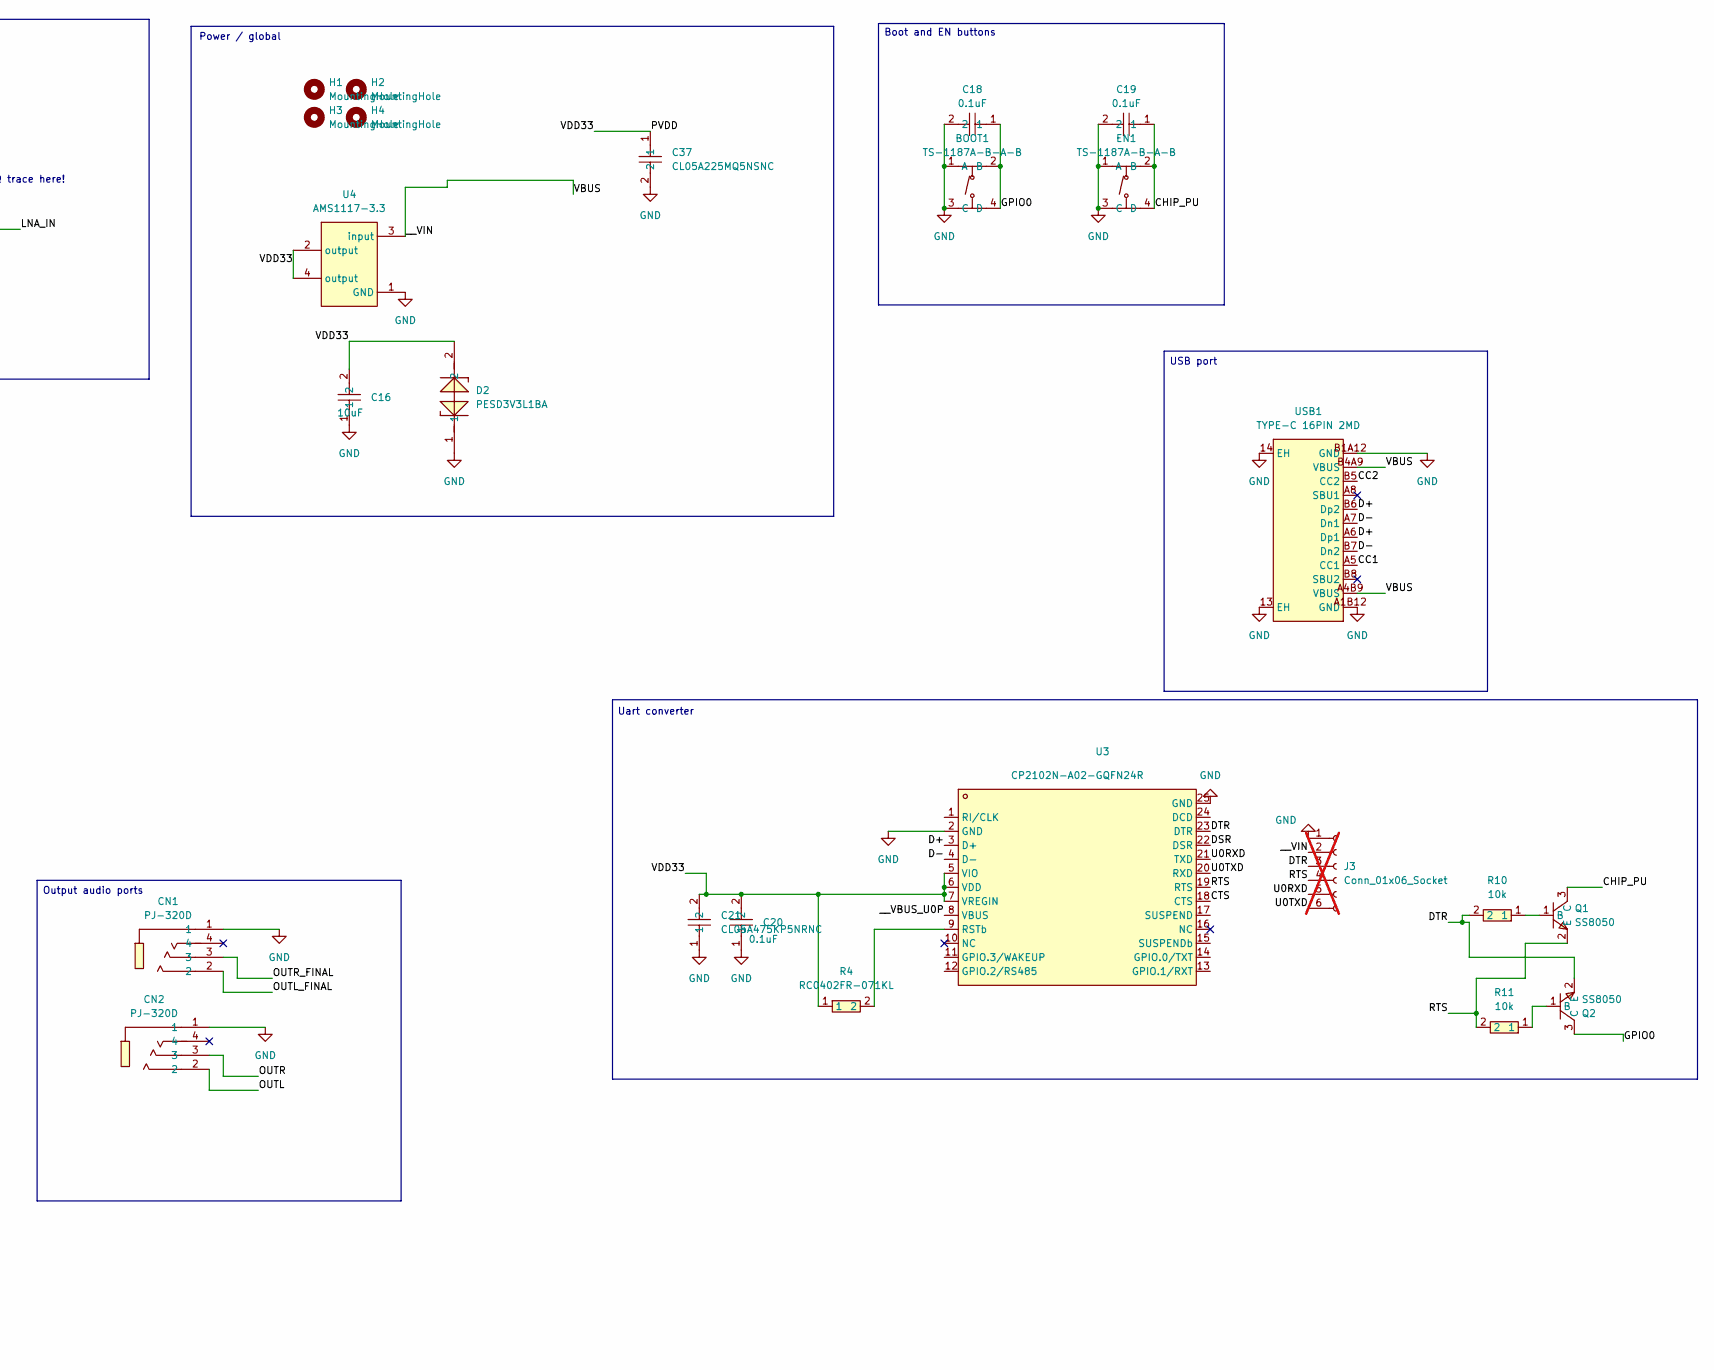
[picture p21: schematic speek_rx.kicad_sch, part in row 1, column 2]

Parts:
AE1: 2450AT18A100E; ANT-SMD_L3.2-W1.6; MPN 2450AT18A100E; LCSC Part C89334
BOOT1: TS-1187A-B-A-B; SW-SMD_4P-L5.1-W5.1-P3.70-LS6.5-TL_H1.5; MPN TS-1187A-B-A-B; LCSC Part C318884
C16, C23, C24, C27, C28, C40: 10uF; C0402; MPN CL05A106MQ5NUNC; LCSC Part C15525
C18, C19, C20, C22, C25, C26, C29, C39: 0.1uF; C0402; MPN CL05B104KO5NNNC; LCSC Part C1525
C21: CL05A475KP5NRNC; C0402; MPN CL05A475KP5NRNC; LCSC Part C23733
C30, C31, C36, C37: CL05A225MQ5NSNC; C0402; MPN CL05A225MQ5NSNC; LCSC Part C12530
C32, C33, C34, C35: 1uF; C0402; MPN CL05A105KA5NQNC; LCSC Part C52923
C38: 1pF; C0402; MPN CC0402BRNPO9BN1R0; LCSC Part C309455
CN1, CN2: PJ-320D; AUDIO-SMD_PJ-320D-1; MPN PJ-320D; LCSC Part C431535
D2: PESD3V3L1BA; SOD-323_L1.7-W1.3-LS2.5-BI-1; MPN PESD3V3L1BA; LCSC Part C2827682
EN1: TS-1187A-B-A-B; SW-SMD_4P-L5.1-W5.1-P3.70-LS6.5-TL_H1.5; MPN TS-1187A-B-A-B; LCSC Part C318884
H1, H2, H3, H4: MountingHole; MountingHole_3.2mm_M3
J3: Conn_01x06_Socket; PinHeader_1x06_P2.54mm_Horizontal; not fitted
J4: Conn_01x04; PinHeader_1x04_P2.54mm_Horizontal; not fitted
JP1: U.FL-R-SMT-1; RF-SMD_FRF05002-JSS103M; MPN U.FL-R-SMT-1(80); LCSC Part C88374
L4: 3.9nH; IND-SMD_L1.0-W0.5-2; MPN LQW15AN3N9B00D; LCSC Part C98062
L5: 2.7nH; L0402; MPN SDCL1005C2N7STDF; LCSC Part C27123
Q1, Q2: SS8050; SOT-23-3_L2.9-W1.5-P1.90-LS2.6-BR; MPN SS8050(RANGE:200-350); LCSC Part C2150
R4: RC0402FR-071KL; R0402; MPN RC0402FR-071KL; LCSC Part C11702
R5: 47k; R0402; MPN 0402WGF4702TCE; LCSC Part C25792
R6: 22k; R0402; MPN 0402WGF2202TCE; LCSC Part C25768
R7, R10, R11: 10k; R0402; MPN 0402WGF1002TCE; LCSC Part C25744
R8: 0402WGF0000TCE; R0402; MPN 0402WGF0000TCE; LCSC Part C17168
R9: 0R; R0603; MPN 0603WAF0000T5E; LCSC Part C21189
U3: CP2102N-A02-GQFN24R; QFN-24_L4.0-W4.0-P0.50-TL-EP2.6; MPN CP2102N-A02-GQFN24R; LCSC Part C969151
U4: AMS1117-3.3; SOT-223-4_L6.5-W3.5-P2.30-LS7.0-BR; MPN AMS1117-3.3; LCSC Part C6186
U5: PCM5102APW; TSSOP-20_L6.5-W4.4-P0.65-LS6.4-BL; MPN PCM5102APW; LCSC Part C1520792
U6: TPA6132A2RTER; WQFN-16_L3.0-W3.0-P0.50-TL-EP1.6; MPN TPA6132A2RTER; LCSC Part C69901
U19: ESP32-PICO-V3-02; QFN-48_L7.0-W7.0-P0.50-BL-EP5.1; MPN ESP32-PICO-V3-02; LCSC Part C908392
USB1: TYPE-C 16PIN 2MD; USB-C-SMD_TYPE-C-16PIN-2MD-073; MPN TYPE-C 16PIN 2MD(073); LCSC Part C2765186

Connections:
/AGND: C26.1, C27.1, C28.1, C29.1, C30.2, U5.3 (CPGND), U5.9 (AGND)
/AMP_ENABLE: R8.2, U6.13 (EN)
/BCK: J4.3, U5.13 (BCK), U19.15 (IO26)
/CAPM: C31.2, U5.4 (CAPM)
/CAPP: C31.1, U5.2 (CAPP)
/CC1: USB1.A5 (CC1)
/CC2: USB1.B5 (CC2)
/CHIP_PU: C19.1, EN1.2 (B), EN1.4 (D), Q1.3 (C), U19.9 (EN)
/CTS: U3.18 (CTS)
/D+: U3.3 (D+), USB1.A6 (Dp1), USB1.B6 (Dp2)
/D-: U3.4 (D-), USB1.A7 (Dn1), USB1.B7 (Dn2)
/DIN: J4.2, U5.14 (DIN), U19.39 (IO22)
/DSR: U3.22 (DSR)
/DTR: J3.3, Q2.2 (E), R10.2, U3.23 (DTR)
/GAIN0: U6.6 (G0)
/GAIN1: U6.7 (G1)
/GPIO0: BOOT1.2 (B), BOOT1.4 (D), C18.1, Q2.3 (C), U19.23 (IO0)
/GPIO25: J4.1, U5.15 (LRCK), U19.14 (IO25)
/LNA_IN: JP1.1 (SIG), R9.2, U19.2 (LNA_IN)
/OUTL: C32.2, CN2.2, U5.6 (OUTL)
/OUTL_FINAL: CN1.2, U6.16 (OUTL)
/OUTR: C33.2, CN2.3, U5.7 (OUTR)
/OUTR_FINAL: CN1.3, U6.5 (OUTR)
/PVDD: C16.2, C20.2, C21.2, C24.1, C25.1, C26.2, C27.2, C28.2, C29.2, C37.1, C39.2, C40.2, D2.2, R4.1, R7.2, R8.1, U3.5 (VIO), U3.6 (VDD), U3.7 (VREGIN), U4.2 (output), U4.4 (output), U5.1 (CPVDD), U5.8 (AVDD), U5.20 (DVDD), U6.14 (VDD), U19.1 (VDDA), U19.3 (VDDA3P3), U19.4 (VDDA3P3), U19.19 (VDD3P3_RTC), U19.37 (VDD3P3_CPU), U19.43 (VDDA), U19.46 (VDDA)
/RTS: J3.4, Q1.2 (E), R11.2, U3.19 (RTS)
/U0RXD: J3.5, U3.21 (TXD), U19.40 (U0RXD/IO3)
/U0TXD: J3.6, U3.20 (RXD), U19.41 (U0TXD/IO1)
/VBUS: J3.2, R6.1, U4.3 (input), USB1.A4B9 (VBUS), USB1.B4A9 (VBUS)
/XSMT: R7.1, U5.17 (XSMT)
/__VBUS_U0P: R5.2, R6.2, U3.8 (VBUS)
GND: BOOT1.1 (A), BOOT1.3 (C), C16.1, C18.2, C19.2, C20.1, C21.1, C22.1, C23.1, C24.2, C25.2, C35.2, C36.2, C37.2, C39.1, C40.1, CN1.1, CN2.1, D2.1, EN1.1 (A), EN1.3 (C), J3.1, J4.4, JP1.2 (GND), JP1.3 (GND), L5.1, R5.1, U3.2 (GND), U3.25 (GND), U4.1 (GND), U5.10 (DEMP), U5.11 (FLT), U5.12 (SCK), U5.16 (FMT), U5.19 (DGND), U6.2 (INL+), U6.3 (INR+), U6.10 (PGND), U6.15 (SGND), U6.17 (EP), U19.49 (GND), USB1.13 (EH), USB1.14 (EH), USB1.A1B12 (GND), USB1.B1A12 (GND)
unnamed: AE1.1 (ANT_1), L4.1
unnamed: C38.1, R9.1
unnamed: C38.2, L4.2, L5.2
unnamed: Q1.1 (B), R10.1
unnamed: Q2.1 (B), R11.1
unnamed: R4.2, U3.9 (RSTb)
unnamed: C22.2, C23.2, U5.18 (LDOO)
unnamed: C30.1, U5.5 (VNEG)
unnamed: C34.2, U6.9 (CPN)
unnamed: C34.1, U6.11 (CPP)
unnamed: C36.1, U6.12 (HPVDD)
unnamed: C35.1, U6.8 (HPVSS)
unnamed: C32.1, U6.1 (INL-)
unnamed: C33.1, U6.4 (INR-)

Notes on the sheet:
DAC
USB port
Headphone amp
Must be 50Ω trace here!
Antenna
ESP chip
Always enabled is probably fine, can connect ts to a gpio if I want to be fancy
Output audio ports
Power / global
Boot and EN buttons
Uart converter

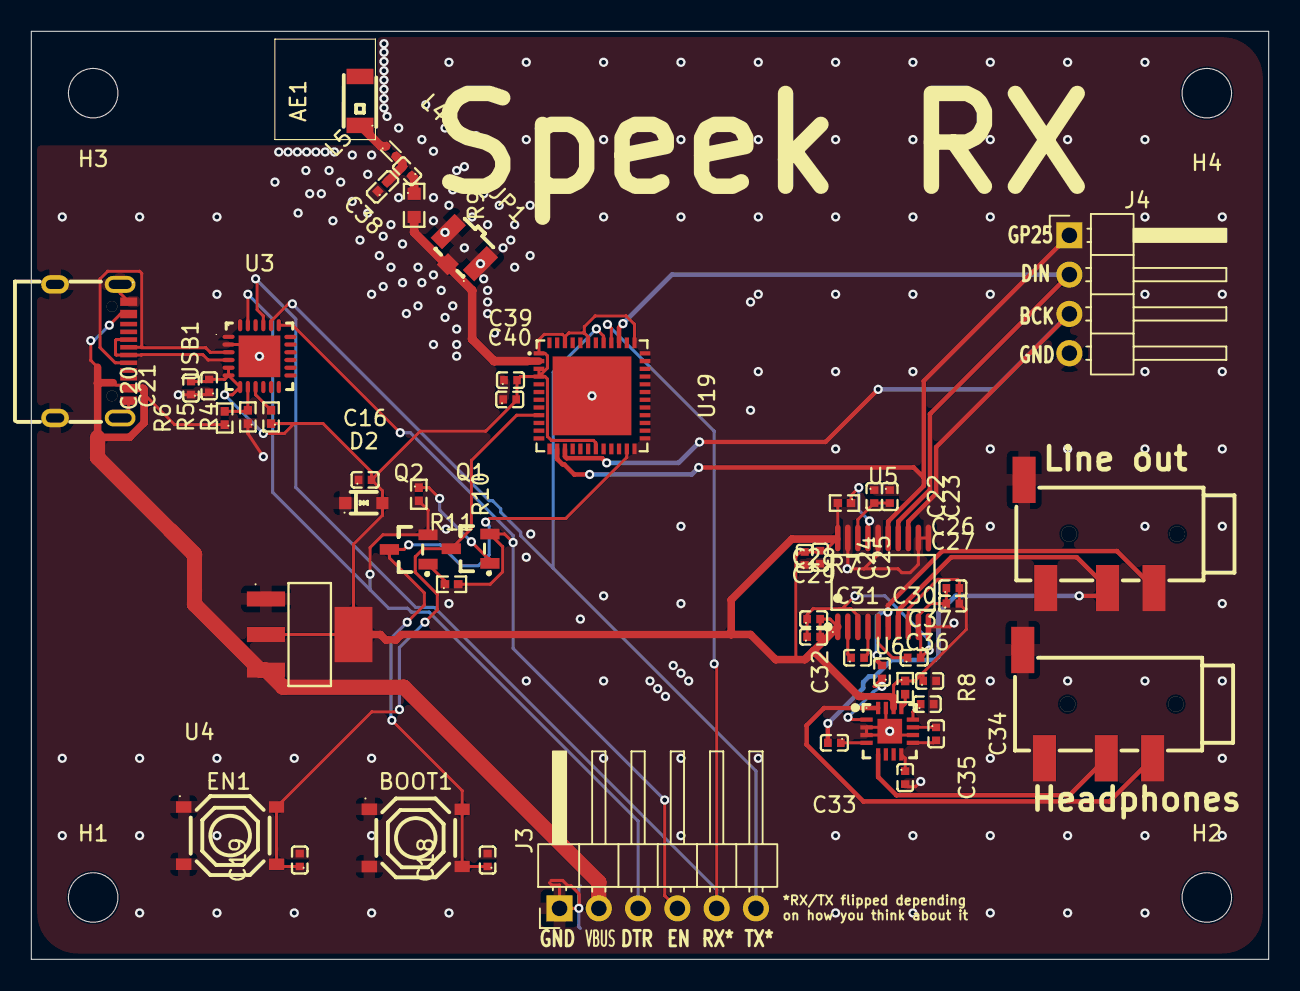
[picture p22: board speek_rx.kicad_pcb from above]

Board: 2 copper layers, 80.0 x 60.0 mm, 55 parts (0 on the bottom side), 39 nets.

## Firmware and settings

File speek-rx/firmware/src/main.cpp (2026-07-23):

#include "BluetoothA2DPSink.h"
BluetoothA2DPSink a2dp_sink;

void setup() {
    i2s_pin_config_t pins = {
        .bck_io_num = 26,   // BCK
        .ws_io_num = 25,    // LRCK
        .data_out_num = 22, // DIN
        .data_in_num = I2S_PIN_NO_CHANGE
    };
    a2dp_sink.set_pin_config(pins);
    a2dp_sink.start("speek-rx");
}
void loop() {}

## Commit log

2026-07-05 chip schematic
    [speek_rx.kicad_pcb, speek_rx.kicad_sch]
2026-07-05 ldo, strappings, uart, USB
    [speek_rx.kicad_sch]
2026-07-06 the speaker and stuff
    [speek_rx.kicad_sch]
2026-07-06 blah footpringh done
    [speek_rx.kicad_pcb, speek_rx.kicad_sch]
2026-07-06 fix tiny bugs
    [speek_rx.kicad_sch]
2026-07-06 easy layout done
    [speek_rx.kicad_pcb, speek_rx.kicad_sch]
2026-07-06 pcb placement done
    [speek_rx.kicad_pcb, speek_rx.kicad_sch]
2026-07-06 start routing ig
    [speek_rx.kicad_pcb, speek_rx.kicad_sch]
2026-07-06 lwk routed the whole thing
    [speek_rx.kicad_pcb]
2026-07-07 vanity vias lol
    [speek_rx.kicad_pcb]
2026-07-07 lwk the whole pcb
    [speek_split.kicad_pcb, speek_split.kicad_sch]
2026-07-07 lwk the pcb
    [speek_psu.kicad_pcb, speek_psu.kicad_sch]
2026-07-09 idk bru
    [speek_amp.kicad_pcb, speek_amp.kicad_sch]
2026-07-19 JST and antenna
    [speek_psu.kicad_pcb, speek_psu.kicad_sch, speek_rx.kicad_pcb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]
2026-07-19 RX I guess
    [speek_rx.kicad_pcb]
2026-07-19 the speek amp schematic
    [speek_amp.kicad_pcb, speek_amp.kicad_sch]
2026-07-21 [Speek Amp] Schematic rework
    [speek_amp.kicad_pcb, speek_amp.kicad_sch, speek_psu.kicad_sch]
2026-07-23 speek rx schematic improvements
    [speek_rx.kicad_sch]
2026-07-23 [Speek amp] Prelim placement!!! [0.62 hours]
    Long bom, many caps to place...
    [speek_amp.kicad_pcb]
2026-07-23 [Speek Amp] routing !! [1.25 hours]
    [speek_amp.kicad_pcb, speek_amp.kicad_sch]
2026-07-24 production files
    [speek_rx_1_bom.csv, speek_rx_1_designators.csv, speek_rx_1_positions.csv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]
2026-07-24 blahhhh lots of docs
    [BOM.csv, speek_amp_1_bom.csv, speek_amp_1_designators.csv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]
2026-07-25 speek RX new board!!
    [speek_rx.kicad_pcb, speek_rx.kicad_sch]
2026-07-25 Speek PSU no longer requires PCBA !!
    [speek_psu.kicad_pcb, speek_psu.kicad_sch]
2026-07-25 dnp d3
    [speek_psu.kicad_pcb, speek_psu.kicad_sch]
2026-07-25 assembly !!
2026-07-26 [fix amp] I am a bit of a stupid
    [speek_amp.kicad_pcb]
